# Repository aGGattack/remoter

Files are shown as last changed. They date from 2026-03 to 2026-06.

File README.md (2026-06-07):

# Bachelor Project - Wireless Remote Controller System

Remote control system for a robot, built around an **Adafruit Feather M0** with an **RFM69 433 MHz** radio, consisting of a handheld remote controller and a robot-side receiver.

---

## Repository Structure

```
bachelor/
├── remoter/                         # Firmware source code
│   ├── Remote/                      # Handheld remote controller
│   │   ├── src/main.cpp             # Main loop, 10Hz control rate
│   │   ├── src/RadioTrans.cpp       # RFM69 radio (TX, ACK)
│   │   ├── src/Joystick.cpp         # Analog joystick driver
│   │   ├── src/OledDis.cpp          # SSD1306 OLED display driver
│   │   ├── include/                 # Headers
│   │   └── platformio.ini           # PlatformIO config
│   │
│   └── RobotSide/                   # Robot-mounted receiver
│       ├── src/main.cpp             # Main loop, serial bridge
│       ├── src/RemoteTransiver.cpp  # RFM69 radio (RX, ACK) + serial
│       ├── include/                 # Headers
│       └── platformio.ini           # PlatformIO config
│
├── UniRemote/                       # Remote controller PCB (KiCad)
│   ├── PCB remote.kicad_sch         # Schematic
│   ├── PCB remote.kicad_pcb         # PCB layout
│   ├── PCB remote.kicad_pro         # Project file
│   └── Remote-footprints.pretty/    # Custom footprints
│
├── UniRobot/                        # Robot receiver PCB (KiCad)
│   ├── UniRobot.kicad_sch           # Schematic
│   ├── UniRobot.kicad_pcb           # PCB layout
│   ├── UniRobot.kicad_pro           # Project file
│   └── Remote-footprints.pretty/    # Custom footprints
│
├── Project tests/                   # RFM69 performance characterization
│   ├── BitRateLatencyTest.py        # Latency vs bitrate (1.2-250 kbps)
│   ├── PackageSizeLatencyTest.py    # Latency vs packet size (5-64 B)
│   ├── MaxDistance/                 # Packet loss vs distance
│   ├── RSSI_Antenna_test/           # RSSI vs distance + antenna length
│   ├── OrrientationTest/            # RSSI vs antenna orientation
│   └── latency_Bitrate_test/        # Plotting scripts
│
├── project_plan/                    # Project plan (LaTeX, diagrams)
├── Bachelor_Contract.pdf
├── appendix_code_listings.tex       # Full source listings for report
├── UniRemote v1.zip, v1.5.zip, ...  # PCB version archives
└── UniRobot v1.zip, v1.5.zip, ...
```

---

## Hardware

| Component | Description |
|---|---|
| **MCU** | Adafruit Feather M0 (ATSAMD21G18A, ARM Cortex-M0+) |
| **Radio** | RFM69HCW 433 MHz transceiver |
| **Display** | SSD1306 128x32 OLED, I2C |
| **Input** | Analog dual-axis joystick + push button (E-stop) |
| **Battery** | LiPo with voltage monitor via A7 |

---

## Firmware

### How It Works

- **Remote** reads joystick X/Y (8-bit), button state, and battery voltage. Transmits 3-byte packets every 100 ms to the robot (NodeID=1). Receives ACK containing robot battery voltage and robot name. Displays RSSI, local & remote battery, and robot name on the OLED.
- **RobotSide** receives joystick packets and forwards them over serial to a Raspberry Pi as `x:<val>, y:<val>, btn:<val>`. Sends ACKs with robot battery and name (parsed from Pi serial input `name:<n>,bat:<v>`). Drives an E-stop output pin.

### Prerequisites

- [PlatformIO](https://platformio.org/)

### Build & Upload

```bash
# Remote controller
cd remoter/Remote
pio run -e adafruit_feather_m0 --target upload

# Robot-side receiver
cd remoter/RobotSide
pio run -e adafruit_feather_m0 --target upload
```

### Serial Monitor

```bash
pio device monitor --baud 115200
```

---

## PCB Design

Both PCBs designed in **KiCad**. To open:

```
# Remote
UniRemote/PCB remote.kicad_pro

# Robot
UniRobot/UniRobot.kicad_pro
```

---

## RF Performance Tests

Python scripts in `Project tests/` characterize the RFM69 link:

| Test | What it measures |
|---|---|
| `BitRateLatencyTest.py` | One-way latency from 1.2 to 250 kbps |
| `PackageSizeLatencyTest.py` | Latency vs payload size at multiple bitrates |
| `MaxDistance/packagelossTest.py` | Packet loss ratio from 20 to 70 m |
| `RSSI_Antenna_test/RSSItest.py` | RSSI vs distance for a given antenna |
| `OrrientationTest/OrrientationsTest.py` | RSSI vs antenna orientation |
| Various `plot_*.py` | Generate plots from collected CSV data |

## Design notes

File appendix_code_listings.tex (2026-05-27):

% =============================================================================
% APPENDIX: Source Code Listings
% =============================================================================
% Fully self-contained -- works directly on Overleaf.
% Drop this file into your project and \input{appendix_code_listings}
% in your report where you want the appendix to appear.
%
% If you already have these packages in your preamble, comment out the
% \usepackage lines below.
% =============================================================================

% ---- Packages (uncomment any NOT already in your preamble) ------------------
% \usepackage{xcolor}
% \usepackage{listings}
% \usepackage{caption}

% ---- Listing style -----------------------------------------------------------
\definecolor{codebg}{rgb}{0.95,0.95,0.97}
\definecolor{codeframe}{rgb}{0.80,0.80,0.85}
\definecolor{stringgreen}{rgb}{0.15,0.55,0.15}
\definecolor{keywordblue}{rgb}{0.10,0.20,0.70}
\definecolor{commentgray}{rgb}{0.35,0.35,0.35}

\lstdefinestyle{appendix}{
  language        = C++,
  basicstyle      = \footnotesize\ttfamily,
  backgroundcolor = \color{codebg},
  frame           = single,
  rulecolor       = \color{codeframe},
  numbers         = left,
  numberstyle     = \tiny\color{gray},
  stepnumber      = 1,
  numbersep       = 8pt,
  tabsize         = 2,
  showspaces      = false,
  showstringspaces = false,
  breaklines      = true,
  breakatwhitespace = true,
  keywordstyle    = \color{keywordblue}\bfseries,
  commentstyle    = \color{commentgray}\itshape,
  stringstyle     = \color{stringgreen},
  captionpos      = t,
  xleftmargin     = 2em,
  framexleftmargin = 1.5em,
}

\lstdefinestyle{appendix-py}{
  style           = appendix,
  language        = Python,
}

\lstdefinestyle{appendix-ini}{
  style           = appendix,
  language        = {[LaTeX]TeX},
}

% =============================================================================
\chapter{Source Code Listings}  \label{app:code}
% =============================================================================

% -----------------------------------------------------------------------------
\section{Remote Controller Firmware (C++)}
% -----------------------------------------------------------------------------

The handheld remote controller firmware runs on an Adafruit Feather~M0
with an RFM69~433\,MHz transceiver, an SSD1306~128$\times$32~OLED display,
and an analog dual-axis joystick.  PlatformIO is used as the build system.

% ---- main.cpp ---------------------------------------------------------------
\begin{lstlisting}[style=appendix, caption={Remote --- main.cpp}, label={lst:remote-main}]
#include <Arduino.h>
#include "OledDis.h"
#include "RadioTrans.h"
#include "Joystick.h"

#define BUTTON_PIN 10
#define VBATPIN A7
#define PWR_CONTROL 5

volatile uint8_t buttonState = 0;

void handleButton() {
  buttonState = !buttonState;
}

void setup() {
  Serial.begin(115200);
  delay(2000);

  pinMode(PWR_CONTROL, OUTPUT);
  digitalWrite(PWR_CONTROL, HIGH);

  attachInterrupt(digitalPinToInterrupt(BUTTON_PIN), handleButton, FALLING);

  Display_init();

  transiver_init();   

  Serial.println("System ready");
}

void loop() {
  uint8_t x, y;
  int8_t RSSI = 0;
  uint8_t battery = 0;
  char robotName[15] = "No connection";

  readJoystick(&x, &y);

  // Remote battery mesurements
  float measuredvbat = analogRead(VBATPIN);
  measuredvbat *= 2;
  measuredvbat *= 3.3;
  measuredvbat /= 1024.0;

  sendData(x, y, buttonState, &battery, robotName, &RSSI);
  Display_draw(robotName, measuredvbat, battery, RSSI);

  delay(100);
}
\end{lstlisting}

% ---- Joystick.cpp -----------------------------------------------------------
\begin{lstlisting}[style=appendix, caption={Remote --- Joystick.cpp}, label={lst:remote-joystick}]
#include <Arduino.h>

void readJoystick(uint8_t *x, uint8_t *y) {
    *x = -analogRead(A0) >> 2;
    *y = -analogRead(A1) >> 2;
}
\end{lstlisting}

% ---- OledDis.cpp ------------------------------------------------------------
\begin{lstlisting}[style=appendix, caption={Remote --- OledDis.cpp}, label={lst:remote-oled}]
#include <Arduino.h>
#include "OledDis.h"
#include <Wire.h>
#include <Adafruit_SSD1306.h>

#define SCREEN_WIDTH 128
#define SCREEN_HEIGHT 32

Adafruit_SSD1306 display(
  SCREEN_WIDTH,
  SCREEN_HEIGHT,
  &Wire,     
  -1
);

void Display_init() {
  Wire.begin();
  delay(100);
  if (!display.begin(SSD1306_SWITCHCAPVCC, 0x3C)) {
    Serial.println("OLED not found");
    while (1);
  }
  Serial.println("OLED found");

  display.clearDisplay();
  display.setRotation(2);
  display.ssd1306_command(SSD1306_DISPLAYON);
  display.ssd1306_command(SSD1306_NORMALDISPLAY);
  display.display();
}

void Display_test() {
  display.clearDisplay();

  display.drawRect(0, 0, 128, 32, SSD1306_WHITE);

  display.drawLine(0, 0, 127, 31, SSD1306_WHITE);

  display.display();
}

void Display_clear() {
  display.clearDisplay();
  display.display();
}

void Display_draw(char *name, float remoteBattery, uint8_t robotBattery, int8_t RSSI) {
  display.clearDisplay();
  display.setTextSize(1);
  display.setTextColor(SSD1306_WHITE);
  display.setCursor(0, 0);

  display.print("Name:");
  display.println(name);

  display.print("R:");
  display.print(remoteBattery, 1);
  display.print("V");

  display.print("B:");
  display.print(robotBattery / 10.0, 1);
  display.println("V");

  display.print("RSSI:");
  display.println(RSSI);

  display.display();
}
\end{lstlisting}

% ---- RadioTrans.cpp ---------------------------------------------------------
\begin{lstlisting}[style=appendix, caption={Remote --- RadioTrans.cpp}, label={lst:remote-radio}]
#include "RadioTrans.h"
#include <SPI.h>
#include <RFM69.h>
#include <RFM69registers.h>

#define RFM69_CS    0
#define RFM69_RST   1
#define RFM69_INT   A4
#define RFM69_DIO2  A3
#define RFM69_DIO3  A5

#define NETWORKID   42
#define NODEID      2
#define TONODEID    1
#define FREQUENCY   RF69_433MHZ
#define LATENCY_PACKET 0x42
#define PACKET_TEST 0x55

RFM69 radio(RFM69_CS, RFM69_INT);

void transiver_init()
{
    pinMode(RFM69_RST, OUTPUT);
    digitalWrite(RFM69_RST, HIGH);
    delay(50);
    digitalWrite(RFM69_RST, LOW);
    delay(50);

    SPI.begin();

    if (!radio.initialize(FREQUENCY, NODEID, NETWORKID))
    {
        Serial.println("RFM69 init FAILED");
        while (1);
    }

    radio.setHighPower();

    Serial.println("RFM69 init OK");
}

bool sendData(uint8_t x, uint8_t y, uint8_t button, uint8_t *battery, char *robotName, int8_t *RSSI)
{
    uint8_t packet[3];
    packet[0] = x;
    packet[1] = y;
    packet[2] = button;

    if (!radio.sendWithRetry(TONODEID, packet, sizeof(packet), 1, 50))
    {
        Serial.println("No ACK received");
        return false;
    }

    *battery = radio.DATA[0];

    for (int i = 0; i < 14; i++)
    {
        robotName[i] = (char)radio.DATA[i + 1];

        if (robotName[i] == '\0')
            break;
    }

    robotName[14] = '\0';

    *RSSI = radio.RSSI;

    return true;
}
\end{lstlisting}

% ---- Joystick.h -------------------------------------------------------------
\begin{lstlisting}[style=appendix, caption={Remote --- Joystick.h}, label={lst:remote-joystick-h}]
#include <Arduino.h>

void readJoystick(uint8_t *x, uint8_t *y);
\end{lstlisting}

% ---- OledDis.h --------------------------------------------------------------
\begin{lstlisting}[style=appendix, caption={Remote --- OledDis.h}, label={lst:remote-oled-h}]
#pragma once
#include <Arduino.h>

void Display_init();
void Display_test();
void Display_clear();
void Display_draw(char *name, float remoteBattery, uint8_t robotBattery, int8_t RSSI);
\end{lstlisting}

% ---- RadioTrans.h -----------------------------------------------------------
\begin{lstlisting}[style=appendix, caption={Remote --- RadioTrans.h}, label={lst:remote-radio-h}]
#ifndef RFM69_H
#define RFM69_H

#include <Arduino.h>

void transiver_init();

bool sendData(uint8_t x, uint8_t y, uint8_t button, uint8_t *battery, char *robotName, int8_t *RSSI);

#endif
\end{lstlisting}

% ---- platformio.ini ---------------------------------------------------------
\begin{lstlisting}[style=appendix-ini, caption={Remote --- platformio.ini}, label={lst:remote-pio}]
[env:adafruit_feather_m0]
platform = atmelsam
board = adafruit_feather_m0
framework = arduino
monitor_speed = 115200
build_flags = -D USB_SERIAL
lib_deps = 
	adafruit/Adafruit SSD1306@^2.5.16
	lowpowerlab/RFM69@^1.6.0
	lowpowerlab/SPIFlash@^101.1.3
\end{lstlisting}

% -----------------------------------------------------------------------------
\section{Robot-Side Firmware (C++)}
% -----------------------------------------------------------------------------

The robot-side firmware runs on a second Adafruit Feather~M0.  It receives
joystick data over the RFM69 link, reads battery voltage and a human-readable
name from a Raspberry Pi over the serial port, and echoes these back to the
remote inside the radio's ACK payload.

% ---- Robot main.cpp ---------------------------------------------------------
\begin{lstlisting}[style=appendix, caption={Robot --- main.cpp}, label={lst:robot-main}]
#include <Arduino.h>
#include <SPI.h>
#include <RFM69.h>
#include "RemoteTransiver.h"

void setup() {
  Serial.begin(115200);
  while (!Serial) delay(10);

  transiver_init();
}

void loop() {
  transiver_receive();
}
\end{lstlisting}

% ---- RemoteTransiver.cpp ----------------------------------------------------
\begin{lstlisting}[style=appendix, caption={Robot --- RemoteTransiver.cpp}, label={lst:robot-trans}]
#include <SPI.h>
#include <RFM69.h>
#include "RemoteTransiver.h"
#include <RFM69registers.h>

#define RFM69_CS   A5
#define RFM69_INT  6
#define RFM69_RST  A4
#define ESTOP      A3
#define LED_PIN    13

#define NETWORKID  42
#define NODEID     1
#define TONODEID   2
#define FREQUENCY  RF69_433MHZ
#define LATENCY_PACKET 0x42
#define PACKET_TEST 0x55

RFM69 radio(RFM69_CS, RFM69_INT);

float batteryVoltage = 0;       
char robotName[16] = "none/con";     
bool piDataReceived = false;     

unsigned long lastReceiveTime = 0;
unsigned long lastNoConnectionPrint = 0;
const unsigned long CONNECTION_TIMEOUT = 1000;

void transiver_init()
{
    pinMode(LED_PIN, OUTPUT);
    pinMode(RFM69_RST, OUTPUT);
    digitalWrite(RFM69_RST, HIGH);
    delay(100);
    digitalWrite(RFM69_RST, LOW);
    delay(100);

    pinMode(ESTOP, OUTPUT);

    if (!radio.initialize(FREQUENCY, NODEID, NETWORKID))
    {
        Serial.println("RFM69 init FAILED");
        while (1);
    }

    radio.setHighPower();

    Serial.println("RFM69 init OK");
    lastReceiveTime = millis();
}

void readPiSerial()
{
    static char line[64];
    static uint8_t idx = 0;

    while (Serial.available())
    {
        char c = Serial.read();
        if (c == '\r') continue;

        if (c == '\n')
        {
            line[idx] = '\0';
            idx = 0;

            // Find "name:" 
            char* namePtr = strstr(line, "name:");
            char* batPtr  = strstr(line, ",bat:");

            if (namePtr && batPtr)
            {
                namePtr += 5; // skip "name:"

                // Copy name up to the comma
                uint8_t i = 0;
                while (namePtr[i] != ',' && namePtr[i] != '\0' && i < 15)
                {
                    robotName[i] = namePtr[i];
                    i++;
                }
                robotName[i] = '\0';

                // Parse float manually
                batPtr += 5; // skip ",bat:"
                batteryVoltage = atof(batPtr);
                piDataReceived = true;

            }

        }
        else
        {
            if (idx < sizeof(line) - 1)
                line[idx++] = c;
            else
                idx = 0;
        }
    }
}

void handleDataPacket(uint8_t x, uint8_t y, uint8_t button)
{

    Serial.print("x:");
    Serial.print(x);
    Serial.print(", y:");
    Serial.print(y);
    Serial.print(", btn:");
    Serial.println(button);

    if (button == 1)
        digitalWrite(ESTOP, HIGH);
    else
        digitalWrite(ESTOP, LOW);
}

void transiver_receive()
{

    readPiSerial();

    if (radio.receiveDone())
    {
        if (radio.ACKRequested())
        {

            uint8_t ackPayload[16];

            // Battery voltage, e.g. 24.3V -> 243
            ackPayload[0] = (uint8_t)(batteryVoltage * 10.0);

            // Copy robot name into remaining bytes
            uint8_t i = 0;
            for (; i < 14 && robotName[i] != '\0'; i++)
            {
                ackPayload[i + 1] = robotName[i];
            }

            // Zero-fill rest
            for (; i < 14; i++)
            {
                ackPayload[i + 1] = 0;
            }

            radio.sendACK(ackPayload, 15);
        }

        uint8_t x      = radio.DATA[0];
        uint8_t y      = radio.DATA[1];
        uint8_t button = radio.DATA[2];

        handleDataPacket(x, y, button);
        lastReceiveTime = millis();
    }

    if (millis() - lastReceiveTime >= CONNECTION_TIMEOUT) {
        if (millis() - lastNoConnectionPrint >= 1000) {
            Serial.println("no connection"); 
            lastNoConnectionPrint = millis();
        }
    }
}
\end{lstlisting}

% ---- RemoteTransiver.h ------------------------------------------------------
\begin{lstlisting}[style=appendix, caption={Robot --- RemoteTransiver.h}, label={lst:robot-trans-h}]
#ifndef RFM69_H
#define RFM69_H

#include <Arduino.h>

void transiver_init();
void transiver_receive();
void readPiSerial();

#endif
\end{lstlisting}

% ---- Robot platformio.ini ---------------------------------------------------
\begin{lstlisting}[style=appendix-ini, caption={Robot --- platformio.ini}, label={lst:robot-pio}]
[env:adafruit_feather_m0]
platform = atmelsam
board = adafruit_feather_m0
framework = arduino
monitor_speed = 115200
build_flags = -D USB_SERIAL
lib_deps = 
	adafruit/Adafruit SSD1306@^2.5.16
	lowpowerlab/RFM69@^1.6.0
	lowpowerlab/SPIFlash@^101.1.3
\end{lstlisting}

% -----------------------------------------------------------------------------
\section{Test and Measurement Scripts (Python)}
% -----------------------------------------------------------------------------

The following Python scripts were used during the project to characterise
the radio link's latency, packet-loss, and signal-strength (RSSI)
performance.  All measurement scripts communicate with the robot-side
Feather~M0 over a serial port and use \texttt{matplotlib} to produce plots.

% ---- test_feather.py --------------------------------------------------------
\begin{lstlisting}[style=appendix-py, caption={Feather serial-communication test}, label={lst:test-feather}]
#!/usr/bin/env python3
"""
Feather M0 Communication Test Script
============================
Usage: python test_feather.py

This script tests serial communication with the Feather M0 (RobotSide).

Setup:
  - Windows: Uses COM8 (change below if different)
  - Linux: Uses /dev/ttyACM1 (change below if different)

Run:
  python test_feather.py

What it does:
  1. Sends "name:TESTBOT,bat:12.34\n" to Feather
  2. Waits for response
  3. Reports what was received

Output examples:
  - "Response: OK" = Feather received and responded
  - "No response" = Feather not receiving data
"""

import serial
import time
import sys

WINDOWS_PORT = 'COM8'
LINUX_PORT = '/dev/ttyACM1'

if sys.platform.startswith('win'):
    SERIAL_PORT = WINDOWS_PORT
elif sys.platform.startswith('linux'):
    SERIAL_PORT = LINUX_PORT
else:
    SERIAL_PORT = '/dev/ttyUSB0'  # Mac

BAUD_RATE = 115200
TIMEOUT = 2

def test_feather():
    print("=== Feather M0 Communication Test ===")
    print(f"Platform: {sys.platform}")
    print(f"Port: {SERIAL_PORT}")
    print(f"Baud: {BAUD_RATE}")
    print("-" * 40)

    try:
        print("Opening serial port...")
        ser = serial.Serial(SERIAL_PORT, BAUD_RATE, timeout=TIMEOUT)
        time.sleep(2)
        print("Port opened!")

        print("\nSending test data...")
        test_msg = "name:TESTBOT,bat:12.34\n"
        ser.write(test_msg.encode())
        print(f"Sent: {test_msg.strip()}")

        print("\nReading response...")
        received_any = False
        
        for i in range(3):
            time.sleep(0.5)
            if ser.in_waiting > 0:
                data = ser.read(ser.in_waiting)
                print(f"Response {i+1}: {data.decode('utf-8', errors='replace').strip()}")
                received_any = True
            else:
                print(f"Attempt {i+1}: No data available")

        if not received_any:
            print("\nNo response received from Feather!")
            print("This means Feather is not responding to the serial data.")

        ser.close()
        print("\n=== Test Complete ===")

    except serial.SerialException as e:
        print(f"\nERROR: {e}")
        print("\nTroubleshooting:")
        print("  - Make sure Feather is connected")
        print("  - Check correct COM port (Windows: COMx, Linux: /dev/ttyACMx)")
        print("  - Close other programs using the port")
        print("  - Try a different USB port")

if __name__ == "__main__":
    test_feather()
\end{lstlisting}

% ---- BitRateLatencyTest.py --------------------------------------------------
\begin{lstlisting}[style=appendix-py, caption={Latency vs.\ bitrate measurement}, label={lst:bitrate-latency}]
import serial
import time
import matplotlib.pyplot as plt
import csv
import re
from datetime import datetime

SERIAL_PORT = "COM8"
BAUD_RATE = 115200

BITRATE_LABEL = "1.2 kbps"   # Change this manually for each test
MEASURE_TIME = 10

timestamp = datetime.now().strftime("%Y%m%d_%H%M%S")

csv_filename = f"latency_{BITRATE_LABEL.replace(' ', '_')}_{timestamp}.csv"
plot_filename = f"latency_{BITRATE_LABEL.replace(' ', '_')}_{timestamp}.png"

ser = serial.Serial(SERIAL_PORT, BAUD_RATE, timeout=1)
time.sleep(2)

rtt_values = []
oneway_values = []

pattern = r"RTT:\s+(\d+)\s+us\s+\|\s+One-way latency:\s+([\d.]+)\s+ms"

print(f"\nRecording latency data for {BITRATE_LABEL}...")

start = time.time()

while time.time() - start < MEASURE_TIME:
    line = ser.readline().decode(errors='ignore').strip()
    match = re.search(pattern, line)

    if match:
        rtt = int(match.group(1))
        latency = float(match.group(2))
        rtt_values.append(rtt)
        oneway_values.append(latency)
        print(f"RTT: {rtt} us | Latency: {latency} ms")

ser.close()

print(f"\nCollected {len(rtt_values)} samples")

with open(csv_filename, mode='w', newline='') as file:
    writer = csv.writer(file)
    writer.writerow(["Sample", "Bitrate", "RTT_us", "OneWayLatency_ms"])
    for i in range(len(rtt_values)):
        writer.writerow([i + 1, BITRATE_LABEL, rtt_values[i], oneway_values[i]])

print(f"CSV saved as: {csv_filename}")

avg_latency = sum(oneway_values) / len(oneway_values)

samples = list(range(1, len(oneway_values) + 1))

plt.figure(figsize=(8,5))
plt.plot(samples, oneway_values, marker='o', label="One-way Latency")
plt.axhline(avg_latency, linestyle='--', label=f"Average = {avg_latency:.3f} ms")
plt.xlabel("Sample Number")
plt.ylabel("Latency (ms)")
plt.title(f"Latency Test - {BITRATE_LABEL}")
plt.grid(True)
plt.legend()
plt.tight_layout()
plt.savefig(plot_filename, dpi=300)
print(f"Plot saved as: {plot_filename}")
plt.show()
\end{lstlisting}

% ---- PackageSizeLatencyTest.py ----------------------------------------------
\begin{lstlisting}[style=appendix-py, caption={Latency vs.\ packet-size measurement}, label={lst:pkt-size-latency}]
import serial
import time
import matplotlib.pyplot as plt
import csv
import re
from datetime import datetime

SERIAL_PORT = "COM8"
BAUD_RATE = 115200

PACKET_SIZE = 5     # Change for each test
BIT_RATE = 115.2
MEASURE_TIME = 10

timestamp = datetime.now().strftime("%Y%m%d_%H%M%S")

csv_filename = f"packet_size_{PACKET_SIZE}B_{BIT_RATE}kb{timestamp}.csv"
plot_filename = f"packet_size_{PACKET_SIZE}B_{BIT_RATE}kb{timestamp}.png"

ser = serial.Serial(SERIAL_PORT, BAUD_RATE, timeout=1)
time.sleep(2)

rtt_values = []
latency_values = []

pattern = r"Size:\s+(\d+)\s+bytes\s+\|\s+RTT:\s+(\d+)\s+us\s+\|\s+One-way latency:\s+([\d.]+)\s+ms"

print(f"\nRecording latency data for packet size = {PACKET_SIZE} bytes")

start = time.time()

while time.time() - start < MEASURE_TIME:
    line = ser.readline().decode(errors='ignore').strip()
    match = re.search(pattern, line)

    if match:
        size = int(match.group(1))
        rtt = int(match.group(2))
        latency = float(match.group(3))
        rtt_values.append(rtt)
        latency_values.append(latency)
        print(f"Size: {size} B | RTT: {rtt} us | Latency: {latency} ms")

ser.close()

print(f"\nCollected {len(latency_values)} samples")

with open(csv_filename, mode='w', newline='') as file:
    writer = csv.writer(file)
    writer.writerow(["Sample", "PacketSize_Bytes", "RTT_us", "OneWayLatency_ms"])
    for i in range(len(latency_values)):
        writer.writerow([i + 1, PACKET_SIZE, rtt_values[i], latency_values[i]])

print(f"CSV saved as: {csv_filename}")

avg_latency = sum(latency_values) / len(latency_values)

samples = list(range(1, len(latency_values) + 1))

plt.figure(figsize=(8,5))
plt.plot(samples, latency_values, marker='o', label="One-way Latency")
plt.axhline(avg_latency, linestyle='--', label=f"Average = {avg_latency:.3f} ms")
plt.xlabel("Sample Number")
plt.ylabel("Latency (ms)")
plt.title(f"Latency vs Time - Packet Size {PACKET_SIZE} Bytes")
plt.grid(True)
plt.legend()
plt.tight_layout()
plt.savefig(plot_filename, dpi=300)
print(f"Plot saved as: {plot_filename}")
plt.show()
\end{lstlisting}

% ---- packagelossTest.py -----------------------------------------------------
\begin{lstlisting}[style=appendix-py, caption={Packet loss vs.\ distance}, label={lst:packet-loss}]
import serial
import time
import matplotlib.pyplot as plt
import csv
from datetime import datetime

SERIAL_PORT = "COM8"
BAUD_RATE = 115200

DISTANCES = list([20, 40, 50, 70])
EXPECTED_PACKETS = 100

timestamp = datetime.now().strftime("%Y%m%d_%H%M%S")

csv_filename = f"packet_loss_test_{timestamp}.csv"
plot_filename = f"packet_loss_plot_{timestamp}.png"

ser = serial.Serial(SERIAL_PORT, BAUD_RATE, timeout=1)
time.sleep(2)

results = {}

for dist in DISTANCES:
    print(f"\nMove robot to {dist} meters")
    input("Press ENTER when ready...")
    print("Waiting for packets...")

    received_packets = set()
    start_time = time.time()

    while time.time() - start_time < 10:
        line = ser.readline().decode(errors='ignore').strip()

        if "Received packet:" in line:
            try:
                packet_num = int(line.split(":")[1])
                received_packets.add(packet_num)
                print(f"{dist}m -> Packet {packet_num}")
            except:
                pass

    received_count = len(received_packets)
    lost_count = EXPECTED_PACKETS - received_count
    loss_percent = (lost_count / EXPECTED_PACKETS) * 100

    results[dist] = {
        "received": received_count,
        "lost": lost_count,
        "loss_percent": loss_percent
    }

    print("\n========== RESULT ==========")
    print(f"Distance: {dist} m")
    print(f"Received: {received_count}")
    print(f"Lost: {lost_count}")
    print(f"Packet Loss: {loss_percent:.1f}%")
    print("============================")

ser.close()

with open(csv_filename, mode='w', newline='') as file:
    writer = csv.writer(file)
    writer.writerow(["Distance_m", "Received_Packets", "Lost_Packets", "Packet_Loss_Percent"])
    for dist in DISTANCES:
        writer.writerow([dist, results[dist]["received"], results[dist]["lost"], results[dist]["loss_percent"]])

print(f"\nCSV saved as: {csv_filename}")

distances = [dist for dist in DISTANCES]
losses = [results[dist]["loss_percent"] for dist in DISTANCES]

plt.figure(figsize=(8, 5))
plt.plot(distances, losses, marker='o')
plt.xlabel("Distance (m)")
plt.ylabel("Packet Loss (%)")
plt.title("Packet Loss vs Distance")
plt.grid(True)
plt.tight_layout()
plt.savefig(plot_filename, dpi=300)
print(f"Plot saved as: {plot_filename}")
plt.show()
\end{lstlisting}

% ---- OrrientationsTest.py ---------------------------------------------------
\begin{lstlisting}[style=appendix-py, caption={RSSI vs.\ antenna orientation}, label={lst:orientation}]
import serial
import time
import matplotlib.pyplot as plt
import csv
from datetime import datetime

SERIAL_PORT = "COM8"
BAUD_RATE = 115200

ORIENTATIONS = ["Front", "Back", "Left", "Right"]
MEASURE_TIME = 10
ANTENNA = "Horizontal_16.5cm"

timestamp = datetime.now().strftime("%Y%m%d_%H%M%S")

csv_filename = f"rssi_orientation_data_{ANTENNA}_{timestamp}.csv"
plot_filename = f"rssi_orientation_plot_{ANTENNA}_{timestamp}.png"

ser = serial.Serial(SERIAL_PORT, BAUD_RATE, timeout=1)
time.sleep(2)

results = {}

def parse_line(line):
    try:
        parts = line.split(",")
        x = int(parts[0].split(":")[1])
        rssi = int(parts[1].split(":")[1])
        return x, rssi
    except:
        return None, None

for orientation in ORIENTATIONS:
    print(f"\nRotate robot to: {orientation}")
    print("Push joystick to start recording...")

    while True:
        line = ser.readline().decode().strip()
        x, rssi = parse_line(line)
        if x is not None and x > 240:
            print(f"Recording {orientation} orientation...")
            break

    rssi_values = []
    start = time.time()

    while time.time() - start < MEASURE_TIME:
        line = ser.readline().decode().strip()
        x, rssi = parse_line(line)
        if rssi is not None:
            rssi_values.append(rssi)

    results[orientation] = rssi_values
    print(f"Collected {len(rssi_values)} samples")

ser.close()

with open(csv_filename, mode='w', newline='') as file:
    writer = csv.writer(file)
    writer.writerow(["Orientation", "Sample_Number", "RSSI_dBm"])
    for orientation in ORIENTATIONS:
        for i, rssi in enumerate(results[orientation]):
            writer.writerow([orientation, i + 1, rssi])

print(f"\nCSV data saved as: {csv_filename}")

orientations = []
means = []
mins = []
maxs = []

for orientation in ORIENTATIONS:
    vals = results[orientation]
    if len(vals) == 0:
        continue
    orientations.append(orientation)
    means.append(sum(vals) / len(vals))
    mins.append(min(vals))
    maxs.append(max(vals))

plt.figure(figsize=(8, 5))
plt.plot(orientations, means, marker='o', label="Average RSSI")
plt.fill_between(range(len(orientations)), mins, maxs, alpha=0.2, label="Variation")
plt.xlabel("Orientation")
plt.ylabel("RSSI (dBm)")
plt.title("RSSI vs Orientation")
plt.grid(True)
plt.legend()
plt.tight_layout()
plt.savefig(plot_filename, dpi=300)
print(f"Plot saved as: {plot_filename}")
plt.show()
\end{lstlisting}

% ---- RSSItest.py ------------------------------------------------------------
\begin{lstlisting}[style=appendix-py, caption={RSSI vs.\ distance and antenna length}, label={lst:rssi-test}]
import serial
import time
import matplotlib.pyplot as plt
import csv
from datetime import datetime

SERIAL_PORT = "COM8"
BAUD_RATE = 115200

DISTANCES = [1, 5, 10, 20, 40]
MEASURE_TIME = 10
ANTENNA = "Horizontal_16.5cm"

timestamp = datetime.now().strftime("%Y%m%d_%H%M%S")

csv_filename = f"rssi_data_{ANTENNA}_{timestamp}.csv"
plot_filename = f"rssi_plot_{ANTENNA}_{timestamp}.png"

ser = serial.Serial(SERIAL_PORT, BAUD_RATE, timeout=1)
time.sleep(2)

results = {}

def parse_line(line):
    try:
        parts = line.split(",")
        x = int(parts[0].split(":")[1])
        rssi = int(parts[1].split(":")[1])
        return x, rssi
    except:
        return None, None

for dist in DISTANCES:
    print(f"\nMove to {dist} meters. Push joystick to start...")

    while True:
        line = ser.readline().decode().strip()
        x, rssi = parse_line(line)
        if x is not None and x > 240:
            print(f"Recording at {dist} m...")
            break

    rssi_values = []
    start = time.time()

    while time.time() - start < MEASURE_TIME:
        line = ser.readline().decode().strip()
        x, rssi = parse_line(line)
        if rssi is not None:
            rssi_values.append(rssi)

    results[dist] = rssi_values
    print(f"Collected {len(rssi_values)} samples")

ser.close()

with open(csv_filename, mode='w', newline='') as file:
    writer = csv.writer(file)
    writer.writerow(["Distance_m", "Sample_Number", "RSSI_dBm"])
    for dist in DISTANCES:
        for i, rssi in enumerate(results[dist]):
            writer.writerow([dist, i + 1, rssi])

print(f"\nCSV data saved as: {csv_filename}")

distances = []
means = []
mins = []
maxs = []

for d in DISTANCES:
    vals = results[d]
    if len(vals) == 0:
        continue
    distances.append(d)
    means.append(sum(vals) / len(vals))
    mins.append(min(vals))
    maxs.append(max(vals))

plt.figure()
plt.plot(distances, means, marker='o', label="Average RSSI")
plt.fill_between(distances, mins, maxs, alpha=0.2, label="Variation")
plt.xlabel("Distance (m)")
plt.ylabel("RSSI (dBm)")
plt.title("RSSI vs Distance")
plt.grid(True)
plt.legend()
plt.tight_layout()
plt.savefig(plot_filename, dpi=300)
print(f"Plot saved as: {plot_filename}")
plt.show()
\end{lstlisting}

% ---- plot_rssi_antenna.py ---------------------------------------------------
\begin{lstlisting}[style=appendix-py, caption={Multi-file RSSI plotting (antenna comparison)}, label={lst:rssi-plot}]
"""
RSSI vs Distance -- comparison across antenna lengths.

Filename format:  rssi_data_*_<LENGTH>cm_<timestamp>.csv
Columns: Distance_m, Sample_Number, RSSI_dBm
"""

import os
import re
import glob
import pandas as pd
import numpy as np
import matplotlib.pyplot as plt
import matplotlib.ticker as ticker
from pathlib import Path
from collections import defaultdict

DATA_DIR = os.path.dirname(os.path.abspath(__file__))
OUTPUT_DIR = DATA_DIR

LENGTH_ORDER = [16.5, 16.7, 16.9, 17.1, 17.3, 17.5, 17.8]

PALETTE = ["#1f77b4", "#ff7f0e", "#2ca02c", "#d62728",
           "#9467bd", "#8c564b", "#e377c2"]

def parse_length(path: str):
    m = re.search(r'_([\d]+[_.][\d]+)cm[_.]', Path(path).name)
    if m:
        return float(m.group(1).replace("_", "."))
    m2 = re.search(r'_(\d+)cm[_.]', Path(path).name)
    if m2:
        return float(m2.group(1))
    return None

def load_all(data_dir: str) -> pd.DataFrame:
    pattern = os.path.join(data_dir, "rssi_data_*.csv")
    files = glob.glob(pattern)
    if not files:
        raise FileNotFoundError(f"No files matching 'rssi_data_*.csv' in {data_dir}")

    by_length = defaultdict(list)
    for f in sorted(files):
        length = parse_length(f)
        if length is None:
            continue
        df = pd.read_csv(f)
        df.columns = [c.strip() for c in df.columns]
        df = df.rename(columns={c: c.lower().replace(" ", "_") for c in df.columns})
        df = df.rename(columns={"distance_m": "distance", "rssi_dbm": "rssi"})
        df["length_cm"] = length
        by_length[length].append(df)

    frames = []
    for length, dfs in sorted(by_length.items()):
        frames.append(pd.concat(dfs, ignore_index=True))
    return pd.concat(frames, ignore_index=True)

def build_stats(df: pd.DataFrame) -> pd.DataFrame:
    g = df.groupby(["length_cm", "distance"])["rssi"]
    stats = pd.DataFrame({
        "mean": g.mean(), "median": g.median(), "std": g.std(),
        "p5": g.quantile(0.05), "p95": g.quantile(0.95), "n": g.count(),
    }).reset_index()
    return stats

def plot_rssi_vs_distance(stats: pd.DataFrame, out_dir: str):
    lengths = sorted(stats["length_cm"].unique(),
                     key=lambda x: LENGTH_ORDER.index(x) if x in LENGTH_ORDER else x)
    fig, ax = plt.subplots(figsize=(9, 6))
    for i, length in enumerate(lengths):
        sub = stats[stats["length_cm"] == length].sort_values("distance")
        color = PALETTE[i % len(PALETTE)]
        marker = ["o", "s", "^", "D", "v", "P", "X"][i % 7]
        ax.plot(sub["distance"], sub["median"],
                color=color, marker=marker, linewidth=2, markersize=7,
                label=f"{length} cm", zorder=3)
        ax.fill_between(sub["distance"], sub["p5"], sub["p95"],
                        alpha=0.08, color=color)
        ax.fill_between(sub["distance"],
                        sub["median"] - sub["std"], sub["median"] + sub["std"],
                        alpha=0.15, color=color)
    ax.set_xscale("log")
    ax.set_xlabel("Distance (m)", fontsize=11)
    ax.set_ylabel("RSSI (dBm)", fontsize=11)
    ax.set_title("RSSI vs Distance -- Antenna Length Comparison", fontsize=12)
    distances = sorted(stats["distance"].unique())
    ax.set_xticks(distances)
    ax.set_xticklabels([f"{d} m" for d in distances])
    ax.xaxis.set_minor_formatter(ticker.NullFormatter())
    ax.legend(title="Antenna length", loc="lower left")
    ax.grid(True, which="both", linestyle="--", alpha=0.4)
    fig.tight_layout()
    fig.savefig(os.path.join(out_dir, "plot_rssi_vs_distance.png"), dpi=150)
    plt.close(fig)

def plot_bar_per_distance(stats: pd.DataFrame, out_dir: str):
    lengths = sorted(stats["length_cm"].unique(),
                     key=lambda x: LENGTH_ORDER.index(x) if x in LENGTH_ORDER else x)
    distances = sorted(stats["distance"].unique())
    n_len = len(lengths)
    x = np.arange(len(distances))
    width = 0.7 / n_len
    offsets = np.linspace(-(n_len - 1) / 2, (n_len - 1) / 2, n_len) * width
    fig, ax = plt.subplots(figsize=(11, 6))
    for i, length in enumerate(lengths):
        sub = stats[stats["length_cm"] == length].sort_values("distance")
        vals = [sub[sub["distance"] == d]["median"].values[0]
                if len(sub[sub["distance"] == d]) else np.nan for d in distances]
        errs = [sub[sub["distance"] == d]["std"].values[0]
                if len(sub[sub["distance"] == d]) else 0 for d in distances]
        ax.bar(x + offsets[i], vals, width, yerr=errs,
               color=PALETTE[i], alpha=0.8, label=f"{length} cm", capsize=3)
    ax.set_xticks(x)
    ax.set_xticklabels([f"{d} m" for d in distances])
    ax.set_ylabel("Median RSSI (dBm)")
    ax.set_title("Median RSSI per Distance -- Antenna Length Comparison")
    ax.legend(loc="lower left")
    ax.grid(axis="y", linestyle="--", alpha=0.4)
    fig.tight_layout()
    fig.savefig(os.path.join(out_dir, "plot_rssi_bar_per_distance.png"), dpi=150)
    plt.close(fig)

def plot_boxplot_far(df: pd.DataFrame, out_dir: str):
    max_dist = df["distance"].max()
    sub = df[df["distance"] == max_dist]
    lengths = sorted(sub["length_cm"].unique(),
                     key=lambda x: LENGTH_ORDER.index(x) if x in LENGTH_ORDER else x)
    groups = [sub[sub["length_cm"] == l]["rssi"].values for l in lengths]
    labels = [f"{l} cm" for l in lengths]
    colors = PALETTE[:len(lengths)]
    fig, ax = plt.subplots(figsize=(9, 5))
    bp = ax.boxplot(groups, tick_labels=labels, patch_artist=True,
                    medianprops={"color": "black", "linewidth": 2})
    for patch, color in zip(bp["boxes"], colors):
        patch.set_facecolor(color)
        patch.set_alpha(0.75)
    ax.set_title(f"RSSI Distribution at {max_dist} m")
    ax.grid(axis="y", linestyle="--", alpha=0.4)
    fig.tight_layout()
    fig.savefig(os.path.join(out_dir, f"plot_rssi_boxplot_{max_dist}m.png"), dpi=150)
    plt.close(fig)

if __name__ == "__main__":
    df = load_all(DATA_DIR)
    stats = build_stats(df)
    os.makedirs(OUTPUT_DIR, exist_ok=True)
    plot_rssi_vs_distance(stats, OUTPUT_DIR)
    plot_bar_per_distance(stats, OUTPUT_DIR)
    plot_boxplot_far(df, OUTPUT_DIR)
\end{lstlisting}

% ---- plot_latency_vs_bitrate.py ---------------------------------------------
\begin{lstlisting}[style=appendix-py, caption={Latency vs.\ bitrate plotting}, label={lst:latency-bitrate-plot}]
"""
Latency vs Bitrate -- fixed packet size (5 B).

Loads all CSVs matching: latency_*kbps*.csv
Columns: Sample, Bitrate (string), RTT_us, OneWayLatency_ms
"""

import os, re, glob
import pandas as pd
import numpy as np
import matplotlib.pyplot as plt
import matplotlib.ticker as ticker
from pathlib import Path

DATA_DIR = os.path.dirname(os.path.abspath(__file__))
OUTPUT_DIR = DATA_DIR
PACKET_SIZE_B = 5
BITRATE_ORDER = [1.2, 9.6, 57.6, 115.2, 250.0]

def load_all_csvs(data_dir: str) -> pd.DataFrame:
    pattern = os.path.join(data_dir, "latency_*kbps*.csv")
    files = glob.glob(pattern)
    if not files:
        raise FileNotFoundError(f"No CSVs matching 'latency_*kbps*.csv' in {data_dir}")
    frames = []
    for f in sorted(files):
        df = pd.read_csv(f)
        df.columns = [c.strip() for c in df.columns]
        col_map = {c: ["sample", "bitrate_str", "RTT_us", "OWL_ms"][i]
                   for i, c in enumerate(df.columns)}
        df = df.rename(columns=col_map)
        frames.append(df)
    combined = pd.concat(frames, ignore_index=True)
    combined["bitrate_kbps"] = combined["bitrate_str"].str.extract(r"([\d.]+)").astype(float)
    return combined

def remove_outliers(df: pd.DataFrame) -> pd.DataFrame:
    clean = []
    for br, g in df.groupby("bitrate_kbps"):
        med = g["RTT_us"].median()
        clean.append(g[g["RTT_us"] < 5 * med])
    return pd.concat(clean, ignore_index=True)

def build_stats(df: pd.DataFrame) -> pd.DataFrame:
    g = df.groupby("bitrate_kbps")["RTT_us"]
    stats = pd.DataFrame({
        "n": g.count(), "mean_ms": g.mean()/1000, "median_ms": g.median()/1000,
        "std_ms": g.std()/1000, "p5_ms": g.quantile(0.05)/1000,
        "p95_ms": g.quantile(0.95)/1000,
    }).reset_index()
    order = {b: i for i, b in enumerate(BITRATE_ORDER)}
    stats["_order"] = stats["bitrate_kbps"].map(order).fillna(999)
    return stats.sort_values("_order").drop(columns="_order").reset_index(drop=True)

def plot_rtt_line(stats: pd.DataFrame, out_dir: str):
    fig, ax = plt.subplots(figsize=(8, 5))
    ax.plot(stats["bitrate_kbps"], stats["median_ms"],
            color="#2196F3", marker="o", linewidth=2, markersize=7, zorder=3,
            label="Median RTT")
    ax.fill_between(stats["bitrate_kbps"], stats["p5_ms"], stats["p95_ms"],
                    alpha=0.15, color="#2196F3", label="5th-95th percentile")
    ax.fill_between(stats["bitrate_kbps"],
                    stats["median_ms"] - stats["std_ms"],
                    stats["median_ms"] + stats["std_ms"],
                    alpha=0.25, color="#2196F3", label=r"$\pm1\sigma$")
    for _, row in stats.iterrows():
        ax.annotate(f"{row['median_ms']:.1f} ms",
                    xy=(row["bitrate_kbps"], row["median_ms"]),
                    xytext=(0, 10), textcoords="offset points", ha="center", fontsize=8)
    ax.set_xscale("log")
    ax.set_xlabel("Bitrate (kbps)")
    ax.set_ylabel("RTT (ms)")
    ax.set_title(f"Round-Trip Time vs Bitrate  |  Packet size = {PACKET_SIZE_B} B")
    ax.set_xticks(stats["bitrate_kbps"])
    ax.set_xticklabels([f"{b:g}" for b in stats["bitrate_kbps"]])
    ax.xaxis.set_minor_formatter(ticker.NullFormatter())
    ax.legend()
    ax.grid(True, which="both", linestyle="--", alpha=0.4)
    fig.tight_layout()
    fig.savefig(os.path.join(out_dir, "plot_rtt_vs_bitrate.png"), dpi=150)
    plt.close(fig)

def plot_owl_line(df: pd.DataFrame, out_dir: str):
    owl = df.groupby("bitrate_kbps")["OWL_ms"]
    owl_stats = pd.DataFrame({
        "median_ms": owl.median(), "std_ms": owl.std(),
        "p5_ms": owl.quantile(0.05), "p95_ms": owl.quantile(0.95),
    }).reset_index()
    order = {b: i for i, b in enumerate(BITRATE_ORDER)}
    owl_stats["_order"] = owl_stats["bitrate_kbps"].map(order).fillna(999)
    owl_stats = owl_stats.sort_values("_order").drop(columns="_order").reset_index(drop=True)
    fig, ax = plt.subplots(figsize=(8, 5))
    ax.plot(owl_stats["bitrate_kbps"], owl_stats["median_ms"],
            color="#4CAF50", marker="s", linewidth=2, markersize=7, zorder=3,
            label="Median one-way latency")
    ax.fill_between(owl_stats["bitrate_kbps"],
                    owl_stats["median_ms"] - owl_stats["std_ms"],
                    owl_stats["median_ms"] + owl_stats["std_ms"],
                    alpha=0.25, color="#4CAF50", label=r"$\pm1\sigma$")
    for _, row in owl_stats.iterrows():
        ax.annotate(f"{row['median_ms']:.1f} ms",
                    xy=(row["bitrate_kbps"], row["median_ms"]),
                    xytext=(0, 10), textcoords="offset points", ha="center", fontsize=8)
    ax.set_xscale("log")
    ax.set_xlabel("Bitrate (kbps)")
    ax.set_ylabel("One-Way Latency (ms)")
    ax.set_title(f"One-Way Latency vs Bitrate  |  Packet size = {PACKET_SIZE_B} B")
    ax.set_xticks(owl_stats["bitrate_kbps"])
    ax.set_xticklabels([f"{b:g}" for b in owl_stats["bitrate_kbps"]])
    ax.xaxis.set_minor_formatter(ticker.NullFormatter())
    ax.legend()
    ax.grid(True, which="both", linestyle="--", alpha=0.4)
    fig.tight_layout()
    fig.savefig(os.path.join(out_dir, "plot_owl_vs_bitrate.png"), dpi=150)
    plt.close(fig)

def plot_boxplot(df: pd.DataFrame, out_dir: str):
    stats = build_stats(df)
    bitrates = stats["bitrate_kbps"].tolist()
    groups = [df[df["bitrate_kbps"] == br]["RTT_us"].values / 1000 for br in bitrates]
    labels = [f"{b:g} kbps" for b in bitrates]
    fig, ax = plt.subplots(figsize=(9, 5))
    bp = ax.boxplot(groups, tick_labels=labels, patch_artist=True,
                    medianprops={"color": "black", "linewidth": 2})
    colors = ["#2196F3", "#4CAF50", "#FF9800", "#9C27B0", "#F44336"]
    for patch, color in zip(bp["boxes"], colors):
        patch.set_facecolor(color); patch.set_alpha(0.7)
    ax.set_title(f"RTT Distribution per Bitrate  |  Packet size = {PACKET_SIZE_B} B")
    ax.grid(axis="y", linestyle="--", alpha=0.4)
    fig.tight_layout()
    fig.savefig(os.path.join(out_dir, "plot_boxplot_bitrate.png"), dpi=150)
    plt.close(fig)

def plot_bar_comparison(df: pd.DataFrame, out_dir: str):
    stats = build_stats(df)
    bitrates = stats["bitrate_kbps"].tolist()
    x = np.arange(len(bitrates))
    owl_med = [df[df["bitrate_kbps"] == br]["OWL_ms"].median() for br in bitrates]
    owl_std = [df[df["bitrate_kbps"] == br]["OWL_ms"].std() for br in bitrates]
    fig, ax = plt.subplots(figsize=(9, 5))
    width = 0.35
    ax.bar(x - width/2, stats["median_ms"], width, yerr=stats["std_ms"],
           capsize=4, color="#2196F3", alpha=0.8, label="RTT")
    ax.bar(x + width/2, owl_med, width, yerr=owl_std,
           capsize=4, color="#4CAF50", alpha=0.8, label="One-Way Latency")
    ax.set_xticks(x)
    ax.set_xticklabels([f"{b:g} kbps" for b in bitrates])
    ax.set_ylabel("Latency (ms)")
    ax.set_title(f"RTT vs One-Way Latency per Bitrate  |  Packet size = {PACKET_SIZE_B} B")
    ax.legend()
    ax.grid(axis="y", linestyle="--", alpha=0.4)
    fig.tight_layout()
    fig.savefig(os.path.join(out_dir, "plot_bar_rtt_owl.png"), dpi=150)
    plt.close(fig)

if __name__ == "__main__":
    df = load_all_csvs(DATA_DIR)
    df = remove_outliers(df)
    os.makedirs(OUTPUT_DIR, exist_ok=True)
    plot_rtt_line(build_stats(df), OUTPUT_DIR)
    plot_owl_line(df, OUTPUT_DIR)
    plot_boxplot(df, OUTPUT_DIR)
    plot_bar_comparison(df, OUTPUT_DIR)
\end{lstlisting}

% ---- plot_latency.py --------------------------------------------------------
\begin{lstlisting}[style=appendix-py, caption={Latency vs.\ packet-size plotting}, label={lst:latency-pktsize-plot}]
"""
Latency comparison across packet sizes and bitrates.

Filename format: packet_size_<SIZE>B_<BITRATE>kb<timestamp>.csv
Columns: test_num, packet_size_B, RTT_us, one_way_us
"""

import os, re, glob
import pandas as pd
import numpy as np
import matplotlib.pyplot as plt
import matplotlib.ticker as ticker
from pathlib import Path

DATA_DIR = os.path.dirname(os.path.abspath(__file__))
OUTPUT_DIR = DATA_DIR

PACKET_SIZES = [5, 16, 32, 48, 64]
BITRATES = [9.6, 57.6, 115.2]

COLORS = {5: "#2196F3", 16: "#4CAF50", 32: "#FF9800", 48: "#9C27B0", 64: "#F44336"}
MARKERS = {9.6: "o", 57.6: "s", 115.2: "^"}
LINESTYLES = {9.6: "-", 57.6: "--", 115.2: ":"}

def parse_filename(path: str):
    name = Path(path).stem
    m = re.search(r'packet_size_(\d+)B_([\d._]+)kb', name)
    if m:
        return int(m.group(1)), float(m.group(2).replace("_", "."))
    return None

def load_all_csvs(data_dir: str):
    pattern = os.path.join(data_dir, "packet_size_*.csv")
    files = glob.glob(pattern)
    if not files:
        raise FileNotFoundError(f"No CSVs matching 'packet_size_*.csv' in {data_dir}")
    data = {}
    for f in sorted(files):
        key = parse_filename(f)
        if key is None:
            continue
        df = pd.read_csv(f)
        df.columns = ["test_num", "packet_size_B", "RTT_us", "one_way_us"]
        median_rtt = df["RTT_us"].median()
        df = df[df["RTT_us"] < 5 * median_rtt]
        data[key] = df
    return data

def summary_table(data: dict):
    rows = []
    for (ps, br), df in sorted(data.items()):
        rows.append({
            "Packet size (B)": ps, "Bitrate (kbps)": br,
            "RTT mean (ms)": df["RTT_us"].mean()/1000,
            "RTT median (ms)": df["RTT_us"].median()/1000,
            "RTT std (ms)": df["RTT_us"].std()/1000,
            "OWL median (ms)": df["one_way_us"].median()/1000,
            "OWL std (ms)": df["one_way_us"].std()/1000,
        })
    return pd.DataFrame(rows)

def plot_rtt_vs_packet_size(stats: pd.DataFrame, out_dir: str):
    fig, ax = plt.subplots(figsize=(8, 5))
    for br in sorted(stats["Bitrate (kbps)"].unique()):
        sub = stats[stats["Bitrate (kbps)"] == br].sort_values("Packet size (B)")
        ax.plot(sub["Packet size (B)"], sub["RTT median (ms)"],
                marker=MARKERS[br], linestyle=LINESTYLES[br],
                linewidth=1.8, markersize=7, label=f"{br} kbps")
        ax.fill_between(sub["Packet size (B)"],
                        sub["RTT median (ms)"] - sub["RTT std (ms)"],
                        sub["RTT median (ms)"] + sub["RTT std (ms)"], alpha=0.10)
    ax.set_xlabel("Packet Size (bytes)")
    ax.set_ylabel("Median RTT (ms)")
    ax.set_title("Round-Trip Time vs Packet Size")
    ax.set_xticks(PACKET_SIZES)
    ax.legend(title="Bitrate")
    ax.grid(True, linestyle="--", alpha=0.4)
    fig.tight_layout()
    fig.savefig(os.path.join(out_dir, "plot_rtt_vs_packet_size.png"), dpi=150)
    plt.close(fig)

def plot_owl_vs_packet_size(stats: pd.DataFrame, out_dir: str):
    fig, ax = plt.subplots(figsize=(8, 5))
    for br in sorted(stats["Bitrate (kbps)"].unique()):
        sub = stats[stats["Bitrate (kbps)"] == br].sort_values("Packet size (B)")
        ax.plot(sub["Packet size (B)"], sub["OWL median (ms)"],
                marker=MARKERS[br], linestyle=LINESTYLES[br],
                linewidth=1.8, markersize=7, label=f"{br} kbps")
        ax.fill_between(sub["Packet size (B)"],
                        sub["OWL median (ms)"] - sub["OWL std (ms)"],
                        sub["OWL median (ms)"] + sub["OWL std (ms)"], alpha=0.10)
    ax.set_xlabel("Packet Size (bytes)")
    ax.set_ylabel("Median One-Way Latency (ms)")
    ax.set_title("One-Way Latency vs Packet Size")
    ax.set_xticks(PACKET_SIZES)
    ax.legend(title="Bitrate")
    ax.grid(True, linestyle="--", alpha=0.4)
    fig.tight_layout()
    fig.savefig(os.path.join(out_dir, "plot_owl_vs_packet_size.png"), dpi=150)
    plt.close(fig)

def plot_grouped_bar(stats: pd.DataFrame, out_dir: str):
    bitrates = sorted(stats["Bitrate (kbps)"].unique())
    packet_sizes = sorted(stats["Packet size (B)"].unique())
    n_br, n_ps = len(bitrates), len(packet_sizes)
    x = np.arange(n_ps)
    width = 0.7 / n_br
    offsets = np.linspace(-(n_br-1)/2, (n_br-1)/2, n_br) * width
    fig, axes = plt.subplots(1, 2, figsize=(13, 5))
    for ax, metric, ylabel in [
        (axes[0], "RTT median (ms)", "Median RTT (ms)"),
        (axes[1], "OWL median (ms)", "Median One-Way Latency (ms)"),
    ]:
        for i, br in enumerate(bitrates):
            sub = stats[stats["Bitrate (kbps)"] == br].sort_values("Packet size (B)")
            vals = [sub[sub["Packet size (B)"] == ps][metric].values[0]
                    if len(sub[sub["Packet size (B)"] == ps]) else 0 for ps in packet_sizes]
            std_col = metric.replace("median", "std")
            errs = [sub[sub["Packet size (B)"] == ps][std_col].values[0]
                    if len(sub[sub["Packet size (B)"] == ps]) else 0 for ps in packet_sizes]
            ax.bar(x + offsets[i], vals, width, yerr=errs, label=f"{br} kbps", capsize=3)
        ax.set_xlabel("Packet Size (bytes)")
        ax.set_ylabel(ylabel)
        ax.set_xticks(x)
        ax.set_xticklabels([f"{ps} B" for ps in packet_sizes])
        ax.legend(title="Bitrate")
        ax.grid(axis="y", linestyle="--", alpha=0.4)
    fig.suptitle("Latency Comparison -- All Packet Sizes and Bitrates")
    fig.tight_layout()
    fig.savefig(os.path.join(out_dir, "plot_grouped_bar.png"), dpi=150)
    plt.close(fig)

def plot_boxplot(data: dict, out_dir: str):
    bitrates = sorted({k[1] for k in data})
    packet_sizes = sorted({k[0] for k in data})
    fig, axes = plt.subplots(1, len(bitrates), figsize=(5*len(bitrates), 5), sharey=True)
    if len(bitrates) == 1:
        axes = [axes]
    for ax, br in zip(axes, bitrates):
        groups = [data[(ps, br)]["RTT_us"].values/1000 for ps in packet_sizes if (ps, br) in data]
        labels = [f"{ps} B" for ps in packet_sizes if (ps, br) in data]
        bp = ax.boxplot(groups, labels=labels, patch_artist=True,
                        medianprops={"color": "black", "linewidth": 2})
        for patch, ps in zip(bp["boxes"], [ps for ps in packet_sizes if (ps, br) in data]):
            patch.set_facecolor(COLORS.get(ps, "#888")); patch.set_alpha(0.75)
        ax.set_title(f"{br} kbps")
        ax.grid(axis="y", linestyle="--", alpha=0.4)
    axes[0].set_ylabel("RTT (ms)")
    fig.suptitle("RTT Distribution -- Grouped by Bitrate")
    fig.tight_layout()
    fig.savefig(os.path.join(out_dir, "plot_boxplot_rtt.png"), dpi=150)
    plt.close(fig)

def plot_heatmap(stats: pd.DataFrame, out_dir: str):
    import matplotlib.colors as mcolors
    for metric, title, fname in [
        ("RTT median (ms)", "Median RTT (ms)", "plot_heatmap_rtt.png"),
        ("OWL median (ms)", "Median One-Way Latency (ms)", "plot_heatmap_owl.png"),
    ]:
        pivot = stats.pivot(index="Packet size (B)", columns="Bitrate (kbps)", values=metric)
        fig, ax = plt.subplots(figsize=(6, 4))
        im = ax.imshow(pivot.values, aspect="auto", cmap="YlOrRd",
                       norm=mcolors.Normalize(vmin=pivot.values.min(), vmax=pivot.values.max()))
        ax.set_xticks(range(len(pivot.columns)))
        ax.set_xticklabels([f"{c} kbps" for c in pivot.columns])
        ax.set_yticks(range(len(pivot.index)))
        ax.set_yticklabels([f"{r} B" for r in pivot.index])
        ax.set_title(f"Heatmap -- {title}")
        for i in range(len(pivot.index)):
            for j in range(len(pivot.columns)):
                val = pivot.values[i, j]
                if not np.isnan(val):
                    ax.text(j, i, f"{val:.2f}", ha="center", va="center", fontsize=9,
                            color="white" if val > pivot.values.max()*0.65 else "black")
        plt.colorbar(im, ax=ax, label=title)
        fig.tight_layout()
        fig.savefig(os.path.join(out_dir, fname), dpi=150)
        plt.close(fig)

if __name__ == "__main__":
    data = load_all_csvs(DATA_DIR)
    stats = summary_table(data)
    os.makedirs(OUTPUT_DIR, exist_ok=True)
    plot_rtt_vs_packet_size(stats, OUTPUT_DIR)
    plot_owl_vs_packet_size(stats, OUTPUT_DIR)
    plot_grouped_bar(stats, OUTPUT_DIR)
    plot_boxplot(data, OUTPUT_DIR)
    plot_heatmap(stats, OUTPUT_DIR)
\end{lstlisting}

\endinput

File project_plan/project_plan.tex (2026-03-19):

\documentclass[a4paper,12pt]{article}
\usepackage[utf8]{inputenc}
\usepackage[T1]{fontenc}
\usepackage[margin=2.5cm]{geometry}
\usepackage{graphicx}
\usepackage{hyperref}
\usepackage{lastpage}
\usepackage{fancyhdr}
\usepackage{datetime}

% Danish language support
\usepackage[danish]{babel}

% Custom commands
\newcommand{\projectID}{107210}
\newcommand{\studentName}{August Binner Becktor}
\newcommand{\studentID}{234396}
\newcommand{\supervisor}{Jens Christian Andersen, jcan@dtu.dk}
\newcommand{\projectDate}{\today}
\newcommand{\duration}{Feb 2 - Jun 8, 2026 (18 weeks)}
\newcommand{\ECTS}{20}

% Title page
\begin{document}

\begin{titlepage}
    \centering
    \vspace*{2cm}
    
    \textbf{DANMARKS TEKNISKE UNIVERSITET} \\
    \textit{Institute of Electrical and Photonic Engineering} \\
    \vspace{2cm}
    
    \textbf{BACHELOR PROJECT PLAN} \\
    \vspace{1cm}
    
    \hrule
    \vspace{1cm}
    
    {\Large\textbf{\projectID}} \\
    \vspace{0.5cm}
    \textit{Design of long-range safety control for autonomous robots} \\
    \hrule
    
    \vspace{2cm}
    
    \begin{tabular}{ll}
        \textbf{Student:} & \studentName \\
        \textbf{Student ID:} & \studentID \\
        \textbf{Supervisor:} & \supervisor \\
        \textbf{Date:} & \projectDate \\
        \textbf{Duration:} & \duration \\
        \textbf{ECTS:} & \ECTS
    \end{tabular}
    
    \vspace{3cm}
    
    \textit{Department of Electrical and Photonic Engineering} \\
    \textit{DTU Space} \\
    \textit{Technical University of Denmark}
    
\end{titlepage}

% Table of contents
\newpage
\tableofcontents
\newpage

% Content sections
\section{Project Description}
\input{sections/description}

\section{Project Scope}
\input{sections/scope}

\section{Problem Analysis}
\input{sections/problem}

\section{Objectives}
\input{sections/objectives}

\section{Deliverables}
\input{sections/deliverables}

\section{Methodology}
\input{sections/methodology}

\section{Time Schedule}
\input{sections/schedule}

\section{Risk Assessment}
\input{sections/risks}

% References
\newpage
\section{References}
\begin{thebibliography}{99}
    \bibitem{dtu} DTU - Technical University of Denmark. \textit{Department of Electrical and Photonic Engineering}. Available at: \url{https://www.dtu.dk/english/education/undergraduate/b-eng-and-bsc-in-engineering}
    \bibitem{project} DTU Project Database. Project ID: \projectID.
\end{thebibliography}

% Appendices
\newpage
\appendix
\section{Appendix A: Supervisor Confirmation}
\textit{To be signed by supervisor}

\vspace{2cm}
\noindent
\begin{tabular}{p{7cm}p{7cm}}
    \textbf{Supervisor signature:} & \textbf{Date:} \\
    & \\
    \hline
    \textit{Line for signature} & \\
\end{tabular}

\end{document}

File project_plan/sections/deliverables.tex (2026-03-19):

The following deliverables are expected from this project:

\subsection*{Hardware Deliverables}
\begin{enumerate}
    \item \textbf{Remote Controller Unit}
    \begin{itemize}
        \item Custom PCB with microcontroller, radio transceiver, joystick controls, and OLED display
        \item 3D-printed enclosure
        \item Battery management system (8+ hour runtime)
    \end{itemize}
    
    \item \textbf{Robot Receiver Unit}
    \begin{itemize}
        \item Custom PCB with microcontroller, radio transceiver, and motor control interface
        \item 3D-printed enclosure
        \item Power management for robot-side operation
    \end{itemize}
    
    \item \textbf{Circuit Diagrams and PCB Layouts}
    \begin{itemize}
        \item Complete schematics for both units
        \item Gerber files for PCB manufacturing
        \item Bill of materials (BOM)
    \end{itemize}
\end{enumerate}

\subsection*{Software Deliverables}
\begin{enumerate}
    \item \textbf{Firmware for Remote Unit}
    \begin{itemize}
        \item Joystick input processing
        \item Radio communication protocol
        \item OLED display driver
        \item Battery monitoring
    \end{itemize}
    
    \item \textbf{Firmware for Robot Unit}
    \begin{itemize}
        \item Radio communication handler
        \item Motor control interface
        \item Communication loss detection
        \item Safety shutdown logic
    \end{itemize}
\end{enumerate}

\subsection*{Documentation Deliverables}
\begin{enumerate}
    \item \textbf{Technical Report} (Bachelor thesis, approx. 40-60 pages)
    \item \textbf{User Manual} describing operation of the system
    \item \textbf{Test Report} documenting validation results
    \item \textbf{Source Code} (documented and version-controlled)
\end{enumerate}

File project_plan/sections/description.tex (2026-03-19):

\subsection*{English}
For outdoor autonomous mobile robots, the current solution relying on a gamepad is too limited. This project aims to develop a long-range wireless remote control system with safety features for autonomous robots. The system must detect loss of communication and cut power to motors, allow manual override of velocity and turn rate, and operate for at least 8 hours on battery. Optionally, the remote should display messages from the robot such as battery status.

The project involves circuit and PCB design, as well as 3D-printed casing for the devices.

\subsection*{Dansk}
For autonome mobile udendørs robotter er den nuværende løsning med en gamepad for begrænset. Dette projekt har til formål at udvikle et langtrækkende trådløst fjernbetjeningssystem med sikkerhedsfunktioner til autonome robotter. Systemet skal detektere tab af kommunikation og slukke for strømmen til motorerne, tillade manuel overstyring af hastighed og svinghastighed og fungere i mindst 8 timer på batteri. Fjernbetjeningen skal eventuelt vise beskeder fra robotten, såsom batteristatus.

Projektet involverer kredsløbs- og PCB-design samt 3D-printet kabinet til enhederne.

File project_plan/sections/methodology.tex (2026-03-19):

The project will follow a structured engineering design methodology:

\subsection*{Phase 1: Research and Planning (Weeks 1-3)}
\begin{itemize}
    \item Literature review of wireless communication protocols (LoRa, RFM69, etc.)
    \item Market analysis of existing remote control solutions
    \item Component selection and evaluation
    \item Initial system architecture design
\end{itemize}

\subsection*{Phase 2: Design (Weeks 4-8)}
\begin{itemize}
    \item Circuit design for remote and robot units
    \item PCB layout and routing
    \item 3D enclosure design (CAD)
    \item Communication protocol definition
    \item Firmware architecture planning
\end{itemize}

\subsection*{Phase 3: Implementation (Weeks 9-13)}
\begin{itemize}
    \item PCB fabrication and assembly
    \item 3D printing of enclosures
    \item Firmware development and testing
    \item Integration testing
\end{itemize}

\subsection*{Phase 4: Testing and Validation (Weeks 14-16)}
\begin{itemize}
    \item Range testing
    \item Safety feature validation
    \item Battery life testing
    \item Performance optimization
\end{itemize}

\subsection*{Phase 5: Documentation (Weeks 17-18)}
\begin{itemize}
    \item Technical report writing
    \item User manual creation
    \item Final presentation preparation
\end{itemize}

\subsection*{Development Approach}
\begin{itemize}
    \item \textbf{Version Control:} Git for source code and documentation
    \item \textbf{Prototyping:} Breadboard testing before PCB design
    \item \textbf{Testing:} Iterative testing throughout development
    \item \textbf{Documentation:} Continuous documentation of design decisions
\end{itemize}

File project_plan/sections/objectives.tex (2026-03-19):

The project objectives are divided into primary and secondary objectives:

\subsection*{Primary Objectives}
\begin{enumerate}
    \item \textbf{Design a long-range wireless communication system} using the 433 MHz band with a minimum range of 500 meters.
    
    \item \textbf{Implement safety shutdown mechanism} that cuts power to robot motors within 100 ms of communication loss detection.
    
    \item \textbf{Develop manual override functionality} allowing the operator to control velocity (forward/reverse) and turn rate (left/right).
    
    \item \textbf{Design battery-powered remote} with minimum 8-hour operation time.
    
    \item \textbf{Design and build custom PCB} for both remote and robot units.
    
    \item \textbf{Design and 3D-print enclosures} for both devices.
\end{enumerate}

\subsection*{Secondary Objectives (Optional)}
\begin{enumerate}
    \item \textbf{Implement bidirectional communication} to display robot status (battery voltage, errors) on the remote.
    
    \item \textbf{Add low battery warning} to the remote display.
    
    \item \textbf{Implement signal strength indicator} (RSSI) on the remote.
\end{enumerate}

\subsection*{Success Criteria}
The project will be considered successful if:
\begin{itemize}
    \item Communication range exceeds 500 meters in open terrain
    \item Motor shutdown occurs within 100 ms of signal loss
    \item Remote operates for minimum 8 hours on a full battery charge
    \item Both units are fully functional prototypes with custom PCBs and enclosures
\end{itemize}

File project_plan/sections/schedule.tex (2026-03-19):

The project spans 18 weeks from February 2, 2026 to June 8, 2026. The following table summarizes the time allocation:

\begin{table}[h]
\centering
\begin{tabular}{|l|c|c|c|}
\hline
\textbf{Phase} & \textbf{Description} & \textbf{Weeks} & \textbf{Duration} \\
\hline
1 & Research and Planning & 1-3 & 3 weeks \\
\hline
2 & Design & 4-8 & 5 weeks \\
\hline
3 & Implementation & 9-13 & 5 weeks \\
\hline
4 & Testing and Validation & 14-16 & 3 weeks \\
\hline
5 & Documentation & 17-18 & 2 weeks \\
\hline
\end{tabular}
\caption{Project Phase Overview}
\end{table}

\subsection*{Detailed Schedule}

\begin{table}[h]
\centering
\begin{tabular}{|l|c|l|}
\hline
\textbf{Task} & \textbf{Week} & \textbf{Deliverable} \\
\hline
Literature Review & 1-2 & Research summary \\
\hline
Component Selection & 2-3 & Component shortlist, initial budget \\
\hline
System Architecture & 3 & System design document \\
\hline
Circuit Design & 4-5 & Schematics complete \\
\hline
PCB Layout & 5-6 & Gerber files submitted \\
\hline
Enclosure Design & 6-7 & 3D models complete \\
\hline
Firmware Development & 7-11 & Source code modules \\
\hline
PCB Assembly & 8-9 & Assembled boards \\
\hline
Enclosure Printing & 10-11 & Printed enclosures \\
\hline
Integration Testing & 12-13 & Working prototype \\
\hline
Range Testing & 14 & Test report \\
\hline
Safety Validation & 14-15 & Safety test results \\
\hline
Report Writing & 16-18 & Draft and final thesis \\
\hline
Final Presentation & 18 & Presentation slides \\
\hline
\end{tabular}
\caption{Detailed Task Schedule}
\end{table}

\begin{figure}[h]
\centering
\textbf{[Insert Gantt Chart Here]}
\caption{Project Gantt Chart}
\end{figure}

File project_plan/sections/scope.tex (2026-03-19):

The project scope includes the following requirements:

\begin{enumerate}
    \item \textbf{Communication Loss Detection:} System must detect when communication is lost and immediately cut power to the robot's motors.
    
    \item \textbf{Manual Control Override:} The remote must allow the operator to take over control of the vehicle, controlling drive velocity and turn rate.
    
    \item \textbf{Power Supply - Robot Side:} The mobile robot shall power the on-board receiver/control unit.
    
    \item \textbf{Power Supply - Remote Side:} The hand-held remote shall be battery powered with at least 8 hours of operation on a fully charged battery.
    
    \item \textbf{Status Display (Optional):} The remote end should be able to display messages from the robot, e.g., remaining battery power.
    
    \item \textbf{Communication Frequency:} The system shall use the 433 MHz band for communication.
    
    \item \textbf{Hardware Development:} The project shall include circuit and PCB design for both the remote and robot units.
    
    \item \textbf{Enclosure Design:} 3D-printed casing shall be designed and produced for both devices.
\end{enumerate}

\subsection*{Out of Scope}
\begin{itemize}
    \item Development of the autonomous navigation algorithms
    \item Integration with existing robot control systems (beyond motor power control)
    \item Production of multiple units beyond the prototype
    \item Regulatory certification (CE, FCC, etc.)
\end{itemize}

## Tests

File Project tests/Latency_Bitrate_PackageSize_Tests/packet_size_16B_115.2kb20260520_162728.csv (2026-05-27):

Sample | PacketSize_Bytes | RTT_us | OneWayLatency_ms
1 | 16 | 4665 | 2.332
2 | 16 | 4788 | 2.394
3 | 16 | 4778 | 2.389
4 | 16 | 4781 | 2.391
5 | 16 | 4789 | 2.395
6 | 16 | 4785 | 2.392
7 | 16 | 4782 | 2.391
8 | 16 | 150760 | 75.38
9 | 16 | 4791 | 2.395
10 | 16 | 4776 | 2.388
11 | 16 | 4793 | 2.397
12 | 16 | 4798 | 2.399
13 | 16 | 4789 | 2.395
14 | 16 | 4789 | 2.395
15 | 16 | 4775 | 2.388
16 | 16 | 4788 | 2.394
17 | 16 | 4797 | 2.398
18 | 16 | 4778 | 2.389
19 | 16 | 4795 | 2.398
20 | 16 | 4783 | 2.391
21 | 16 | 4797 | 2.398
22 | 16 | 4784 | 2.392
23 | 16 | 4783 | 2.391
24 | 16 | 4790 | 2.395
25 | 16 | 4804 | 2.402
26 | 16 | 4778 | 2.389
27 | 16 | 4773 | 2.386
28 | 16 | 4791 | 2.395
29 | 16 | 4779 | 2.389
30 | 16 | 4787 | 2.394
31 | 16 | 4775 | 2.388
32 | 16 | 4806 | 2.403
33 | 16 | 4799 | 2.399
34 | 16 | 4789 | 2.395
35 | 16 | 4789 | 2.395
36 | 16 | 4797 | 2.398
37 | 16 | 4801 | 2.401
38 | 16 | 4799 | 2.399
39 | 16 | 4802 | 2.401
40 | 16 | 4797 | 2.398
41 | 16 | 4786 | 2.393
42 | 16 | 4800 | 2.4
43 | 16 | 4781 | 2.391
44 | 16 | 4782 | 2.391
45 | 16 | 4784 | 2.392
46 | 16 | 4801 | 2.401
47 | 16 | 4802 | 2.401
48 | 16 | 4791 | 2.395
49 | 16 | 4773 | 2.386
50 | 16 | 4780 | 2.39
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

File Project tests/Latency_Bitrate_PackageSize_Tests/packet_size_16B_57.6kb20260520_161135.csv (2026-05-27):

Sample | PacketSize_Bytes | RTT_us | OneWayLatency_ms
1 | 16 | 7669 | 3.835
2 | 16 | 31642 | 15.821
3 | 16 | 7828 | 3.914
4 | 16 | 7819 | 3.909
5 | 16 | 7829 | 3.914
6 | 16 | 7838 | 3.919
7 | 16 | 7819 | 3.909
8 | 16 | 7840 | 3.92
9 | 16 | 7821 | 3.911
10 | 16 | 7839 | 3.92
11 | 16 | 7816 | 3.908
12 | 16 | 7839 | 3.92
13 | 16 | 7811 | 3.905
14 | 16 | 7822 | 3.911
15 | 16 | 7839 | 3.92
16 | 16 | 7827 | 3.914
17 | 16 | 7821 | 3.911
18 | 16 | 7821 | 3.911
19 | 16 | 7839 | 3.92
20 | 16 | 7824 | 3.912
21 | 16 | 76344 | 38.172
22 | 16 | 7847 | 3.924
23 | 16 | 7839 | 3.92
24 | 16 | 7828 | 3.914
25 | 16 | 7825 | 3.912
26 | 16 | 7820 | 3.91
27 | 16 | 7829 | 3.914
28 | 16 | 7825 | 3.912
29 | 16 | 7837 | 3.918
30 | 16 | 7821 | 3.911
31 | 16 | 7830 | 3.915
32 | 16 | 7828 | 3.914
33 | 16 | 7840 | 3.92
34 | 16 | 7831 | 3.915
35 | 16 | 7830 | 3.915
36 | 16 | 7832 | 3.916
37 | 16 | 7841 | 3.921
38 | 16 | 7831 | 3.915
39 | 16 | 7819 | 3.909
40 | 16 | 7828 | 3.914
41 | 16 | 7818 | 3.909
42 | 16 | 7835 | 3.918
43 | 16 | 7821 | 3.911
44 | 16 | 7839 | 3.92
45 | 16 | 7827 | 3.914
46 | 16 | 7845 | 3.922
47 | 16 | 7827 | 3.914
48 | 16 | 7829 | 3.914
49 | 16 | 7824 | 3.912
50 | 16 | 7831 | 3.915
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

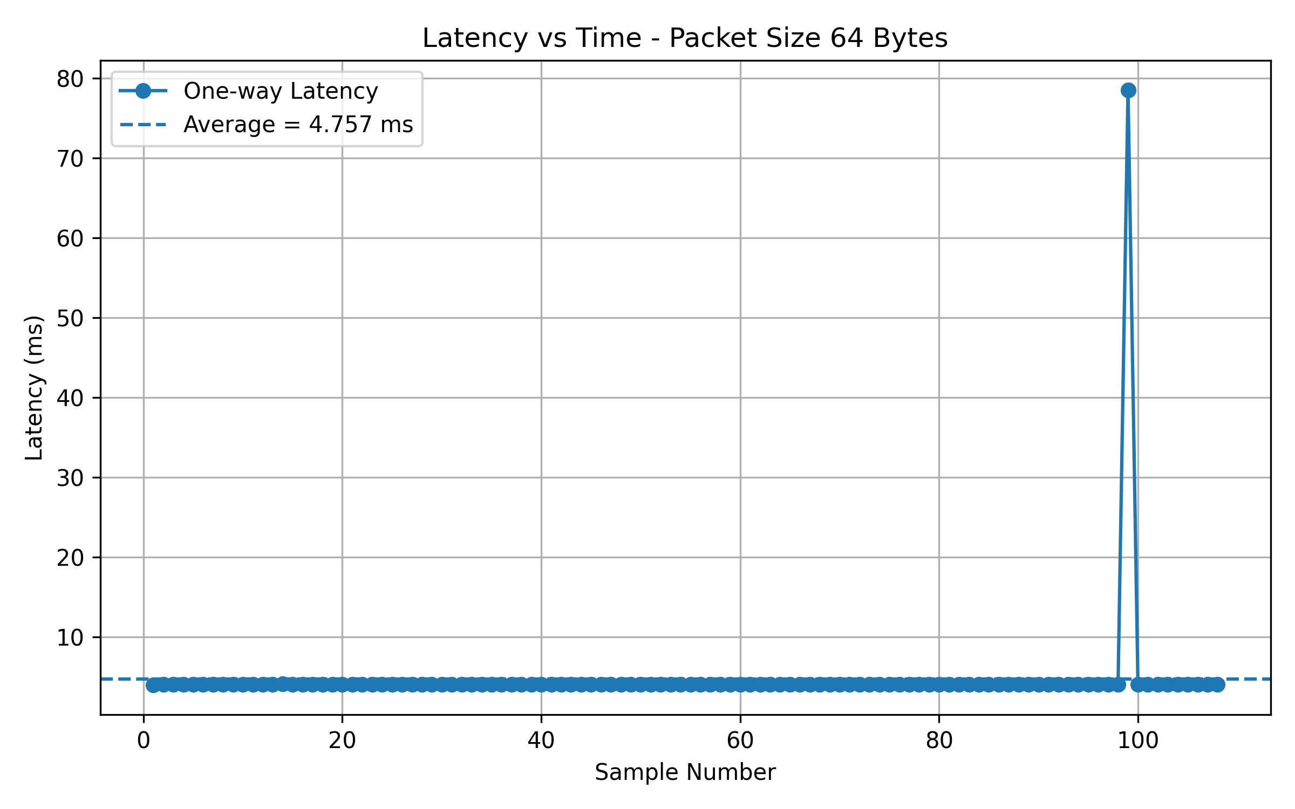
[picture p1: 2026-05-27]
Project tests/Latency_Bitrate_PackageSize_Tests/packet_size_64B_115.2kb20260520_162340.png

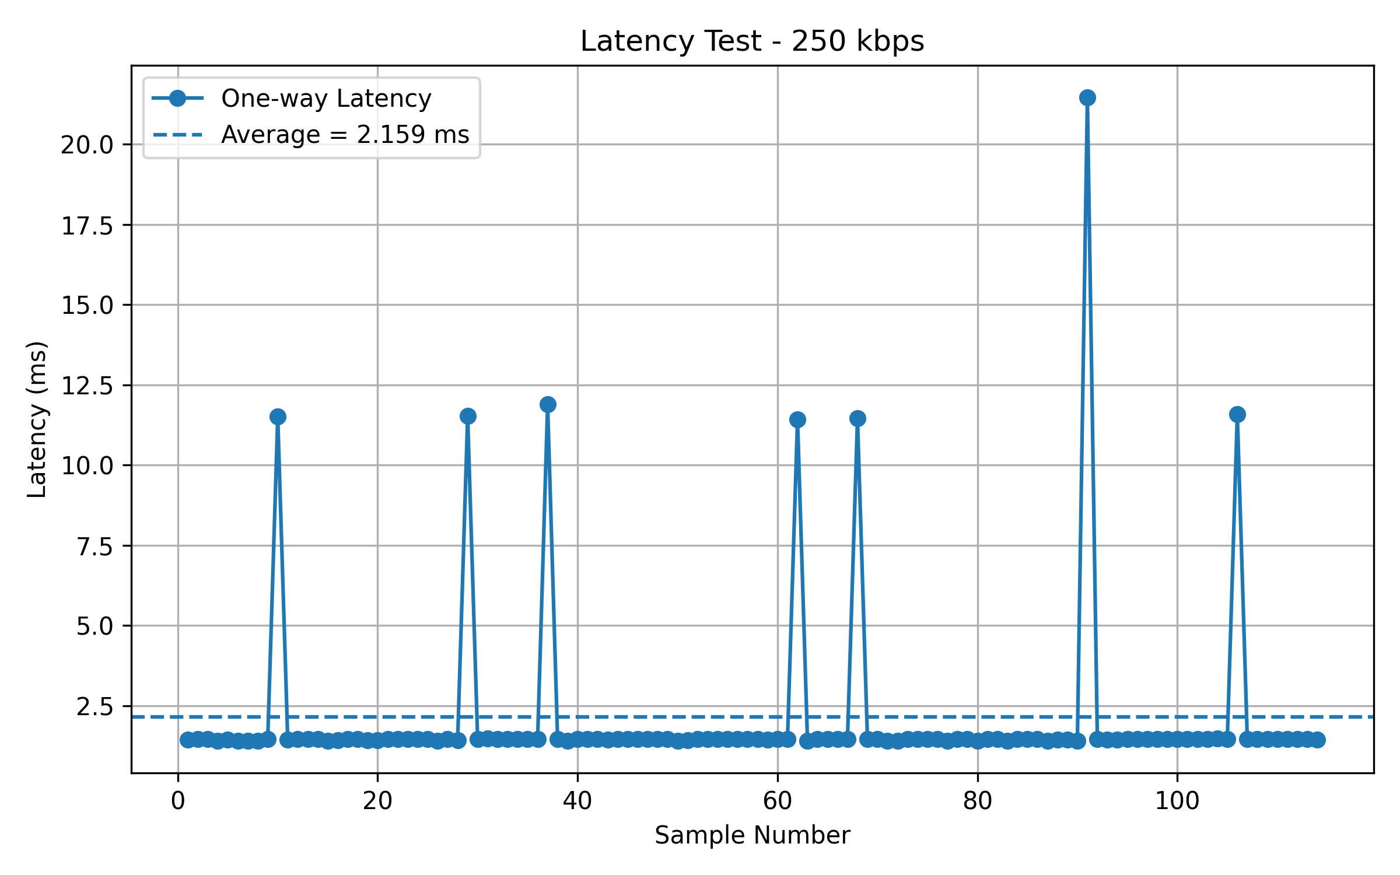
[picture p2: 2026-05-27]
Project tests/latency_Bitrate_test/latency_250_kbps_20260520_151243.png

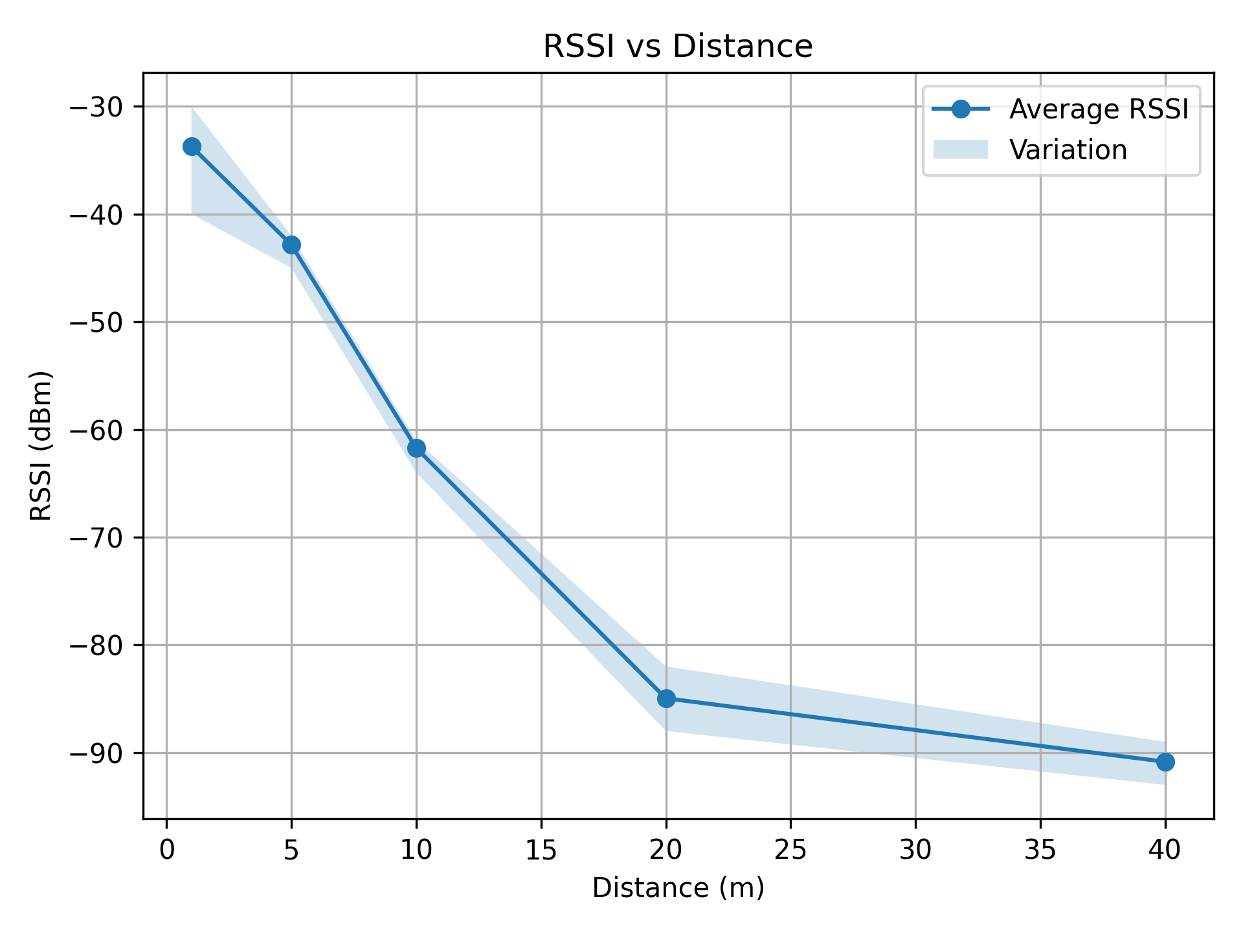
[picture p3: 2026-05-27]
Project tests/RSSI_Antenna_test/rssi_plot_Horizontal_16.7cm_20260521_132743.png

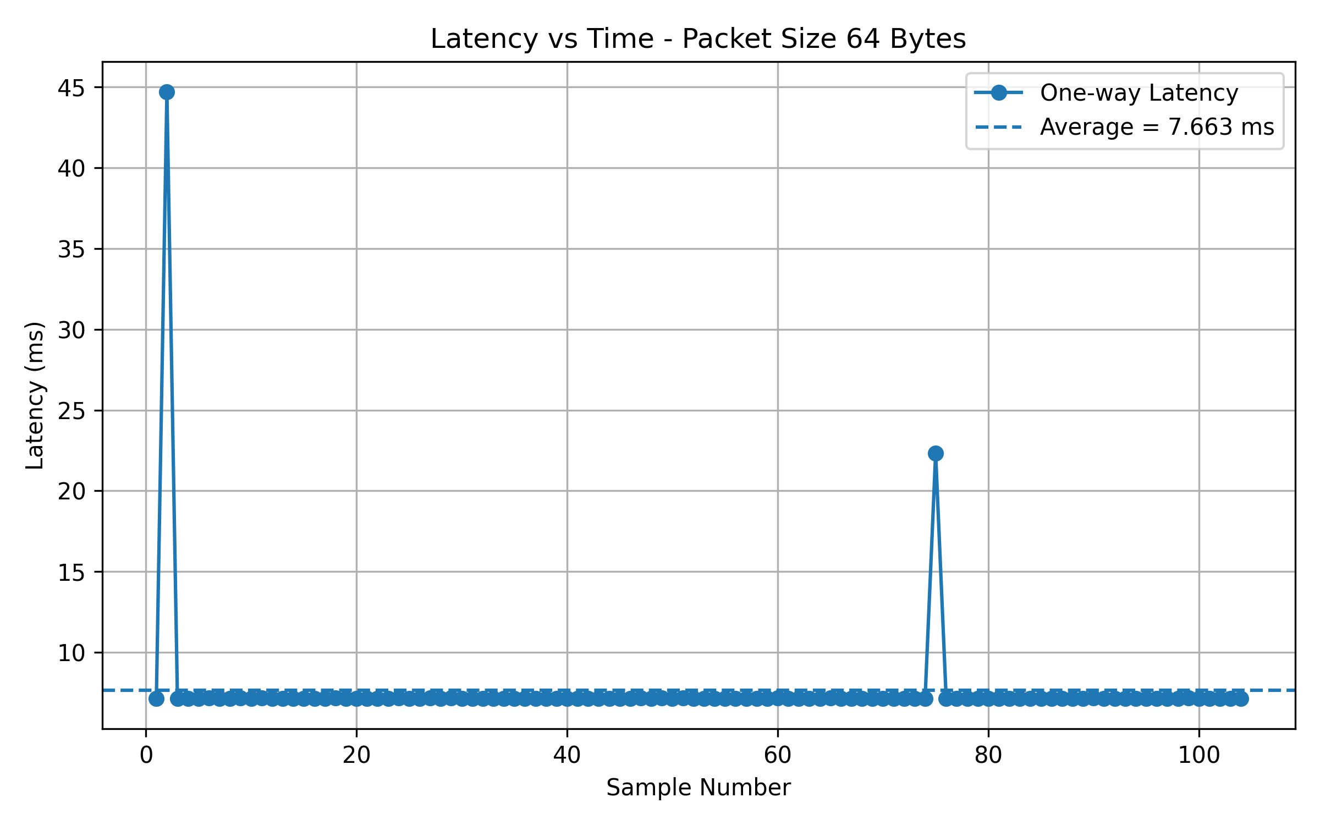
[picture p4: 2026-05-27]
Project tests/Latency_Bitrate_PackageSize_Tests/packet_size_64B_57.6kb20260520_160848.png

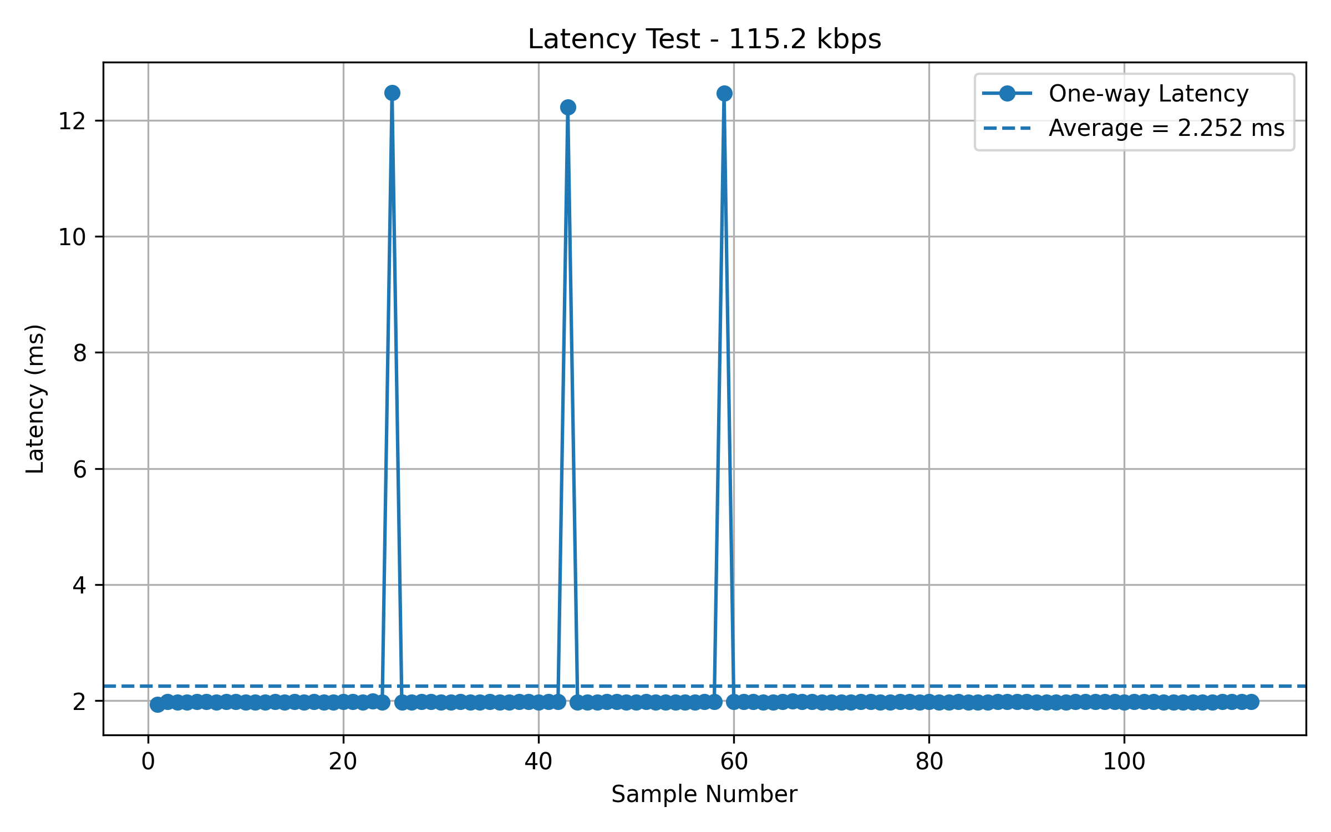
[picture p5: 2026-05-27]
Project tests/latency_Bitrate_test/latency_115.2_kbps_20260520_150932.png

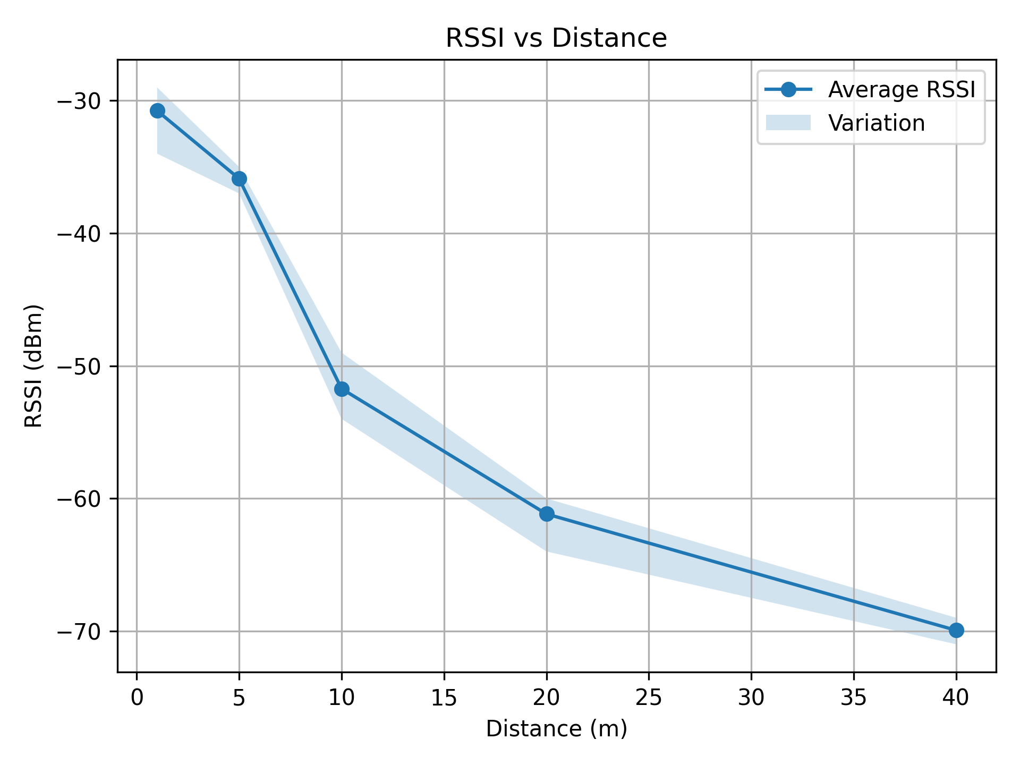
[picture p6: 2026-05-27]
Project tests/RSSI_Antenna_test/rssi_plot_Horizontal_17.1cm_20260521_123817.png

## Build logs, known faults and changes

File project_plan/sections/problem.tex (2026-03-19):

Current remote control solutions for outdoor autonomous mobile robots rely on gamepad controllers, which present several limitations:

\subsection*{Limitations of Current Solution}
\begin{itemize}
    \item \textbf{Limited Range:} Standard gamepads using Bluetooth or 2.4 GHz wireless have very limited range (typically 10-30 meters), insufficient for outdoor operations.
    
    \item \textbf{No Safety Features:} Consumer-grade gamepads lack built-in safety mechanisms for communication loss detection.
    
    \item \textbf{Power Consumption:} Gamepads typically have short battery life, unsuitable for extended outdoor deployments.
    
    \item \textbf{No Feedback:} Standard gamepads cannot receive data from the robot (battery status, errors, etc.).
    
    \item \textbf{Noisy Environments:} 2.4 GHz band is crowded and susceptible to interference.
\end{itemize}

\subsection*{Problem Statement}
The current gamepad-based control system is inadequate for outdoor autonomous mobile robots that require:
\begin{itemize}
    \item Long-range reliable communication
    \item Automatic safety shutdown on communication loss
    \item Extended battery life (8+ hours)
    \item Bidirectional communication for status updates
\end{itemize}

This project addresses these limitations by designing a custom long-range remote control system with safety features.

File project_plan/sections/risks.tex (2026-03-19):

Risk assessment identifies potential issues and mitigation strategies:

\begin{table}[h]
\centering
\begin{tabular}{|p{3cm}|p{4cm}|p{4cm}|p{2cm}|}
\hline
\textbf{Risk} & \textbf{Description} & \textbf{Mitigation} & \textbf{Impact} \\
\hline
PCB Manufacturing Delays & PCB fabrication takes longer than expected & Order PCBs early; have breadboard backup & High \\
\hline
Component Availability & Key components out of stock & Order all components at start of design phase & High \\
\hline
Range Insufficient & Communication range below 500m & Use higher gain antennas; optimize protocol & Medium \\
\hline
Battery Life Below Target & Remote doesn't achieve 8-hour runtime & Optimize firmware; use larger battery & Medium \\
\hline
Safety Feature Failure & Motor cutoff doesn't work reliably & Redundant safety systems; extensive testing & High \\
\hline
Schedule Overrun & Tasks take longer than planned & Build in buffer time; prioritize critical tasks & Medium \\
\hline
Firmware Bugs & Software issues cause system failures & Extensive testing; modular development & Medium \\
\hline
3D Print Failures & Enclosure prints fail or don't fit & Multiple prototypes; adjustable design & Low \\
\hline
\end{tabular}
\caption{Risk Assessment Matrix}
\end{table}

\subsection*{Contingency Plans}

\begin{enumerate}
    \item \textbf{If PCBs are delayed:} Use breadboard/wire-wrap prototypes to continue firmware development
    \item \textbf{If range is insufficient:} Implement range extender techniques (higher antenna, lower data rate)
    \item \textbf{If battery life is insufficient:} Switch to larger battery pack; implement power-saving modes
    \item \textbf{If safety feature fails testing:} Add redundant microcontroller watchdog; implement failsafe modes
\end{enumerate}

\subsection*{Project Risks - Priority Actions}
\begin{itemize}
    \item \textbf{Priority 1:} Ensure safety shutdown mechanism is thoroughly tested
    \item \textbf{Priority 2:} Verify 500m range capability early in testing phase
    \item \textbf{Priority 3:} Complete PCB design with sufficient time for manufacturing
\end{itemize}

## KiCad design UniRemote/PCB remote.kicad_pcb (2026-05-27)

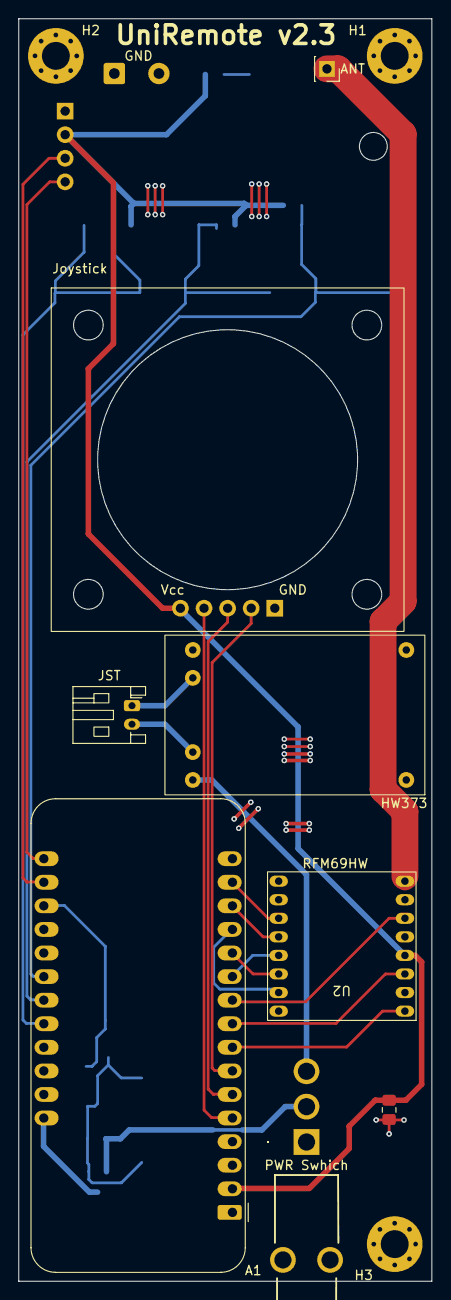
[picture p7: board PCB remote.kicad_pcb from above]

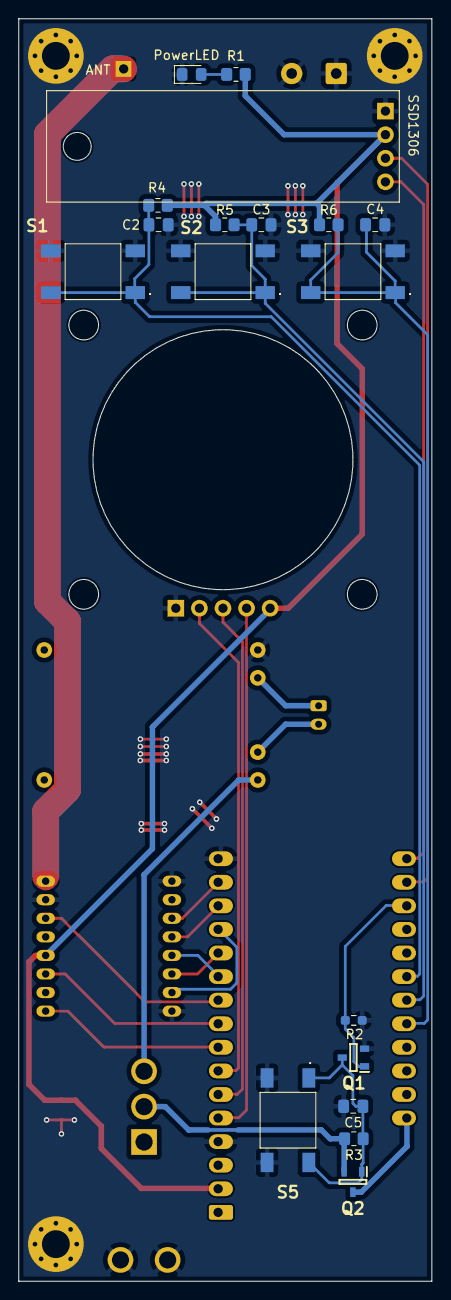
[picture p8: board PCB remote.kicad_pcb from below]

Board: 2 copper layers, 44.5 x 136.0 mm, 30 parts (18 on the bottom side), 27 nets.

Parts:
A1: Adafruit_Feather_M0_Adalogger; Adafruit_Feather
ANT: Conn_01x01; PinSocket_1x01_P2.54mm_Vertical
C1, C5: 10uF; C_0805_2012Metric_Pad1.18x1.45mm_HandSolder
C2, C3, C4: 100nF; C_0805_2012Metric_Pad1.18x1.45mm_HandSolder
D1: LED; LED_0805_2012Metric_Pad1.15x1.40mm_HandSolder
GND: Conn_01x02_Socket; SolderWire-0.5sqmm_1x02_P4.8mm_D0.9mm_OD2.3mm
H1, H2, H3: MountingHole_Pad; MountingHole_3mm_Pad_Via
HW373: HW373
JST: 02_Socket; JST_PH_S2B-PH-K_1x02_P2.00mm_Horizontal
PWR Swhich: 100SP1T1B1M7QEH; 100SP1T1B1M7QEH(redSwitch)
Q1: BSS138; nmos
Q2: PMV28XPEAR; Pmos
R1: 280; R_0805_2012Metric_Pad1.20x1.40mm_HandSolder
R2: 47k; R_0603_1608Metric_Pad0.98x0.95mm_HandSolder
R3: 220k; R_0805_2012Metric_Pad1.20x1.40mm_HandSolder
R4, R5, R6: 10k; R_0805_2012Metric_Pad1.20x1.40mm_HandSolder
S1, S2, S3, S5: TL3301TF160QG
SSD1306: SSD1306; SSD1306(128x32)
U2: RFM69HW; RFM69HCW(homemade)
U3: Joystick

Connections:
+3.3V: A1.2 (3V3), C1.2, R1.1, R4.1, R5.1, R6.1, SSD1306.2 (VCC), U2.4 (3.3V), U3.5 (VCC)
+BATT: A1.28 (VBAT), Q2.3 (D)
/B-D10-S1: A1.22 (D10), C2.1, R4.2, S1.1 (COM_1), S1.2 (COM_2)
/B-D11-S2: A1.23 (D11), C3.1, R5.2, S2.1 (COM_1), S2.2 (COM_2)
/B-D12-S3: A1.24 (D12), C4.1, R6.2, S3.1 (COM_1), S3.2 (COM_2)
/J-A0-Sel: A1.7 (A2), U3.2 (Sel)
/J-A1-Yout: A1.6 (A1), U3.3 (Yout)
/J-A2-Xout: A1.5 (DAC0/A0), U3.4 (Xout)
/P-S4-BAT: PWR Swhich.2 (COM), Q2.2 (S), R3.1
/P-USBC-S4: HW373.3 (out+), PWR Swhich.3 (NO)
/R-A3-D02: A1.8 (A3), U2.1 (DIO2)
/R-A4-DO0: A1.9 (A4), U2.3 (DIO0)
/R-A5-DO3: A1.10 (A5), U2.6 (DIO3)
/R-D0-NSS: A1.14 (RX/D0), U2.12 (NSS)
/R-D1-RT: A1.15 (TX/D1), U2.11 (RESET)
/R-D22-MISO: A1.13 (MISO/D22), U2.15 (MISO)
/R-D23-MOSI: A1.12 (MOSI/D23), U2.14 (MOSI)
/R-D24-SCK: A1.11 (SCK/D24), U2.13 (SCK)
/SCL: A1.18 (SCL/D21), SSD1306.3 (SCK)
/SDA: A1.17 (SDA/D20), SSD1306.4 (SDA)
GND: A1.4 (GND), A1.16 (GND), C1.1, C2.2, C3.2, C4.2, C5.2, D1.1 (K), GND.1, GND.2, H1.1, H2.1, H3.1, HW373.4 (out-), PWR Swhich.4 (MH1), PWR Swhich.5 (MH2), Q1.2 (S), R2.2, S1.3 (NO_1), S1.4 (NO_2), S2.3 (NO_1), S2.4 (NO_2), S3.3 (NO_1), S3.4 (NO_2), S5.3 (NO_1), S5.4 (NO_2), SSD1306.1 (GND), U2.7 (GND), U2.9 (GND), U2.16 (GND), U3.1 (GND)
unnamed: D1.2 (A), R1.2
unnamed: ANT.1, U2.8 (ANA)
unnamed: HW373.2 (b-), JST.1
unnamed: HW373.1 (b+), JST.2
unnamed: C5.1, Q1.3 (D), Q2.1 (G), R3.2, S5.1 (COM_1), S5.2 (COM_2)
PWRC: A1.19 (D5), Q1.1 (G), R2.1

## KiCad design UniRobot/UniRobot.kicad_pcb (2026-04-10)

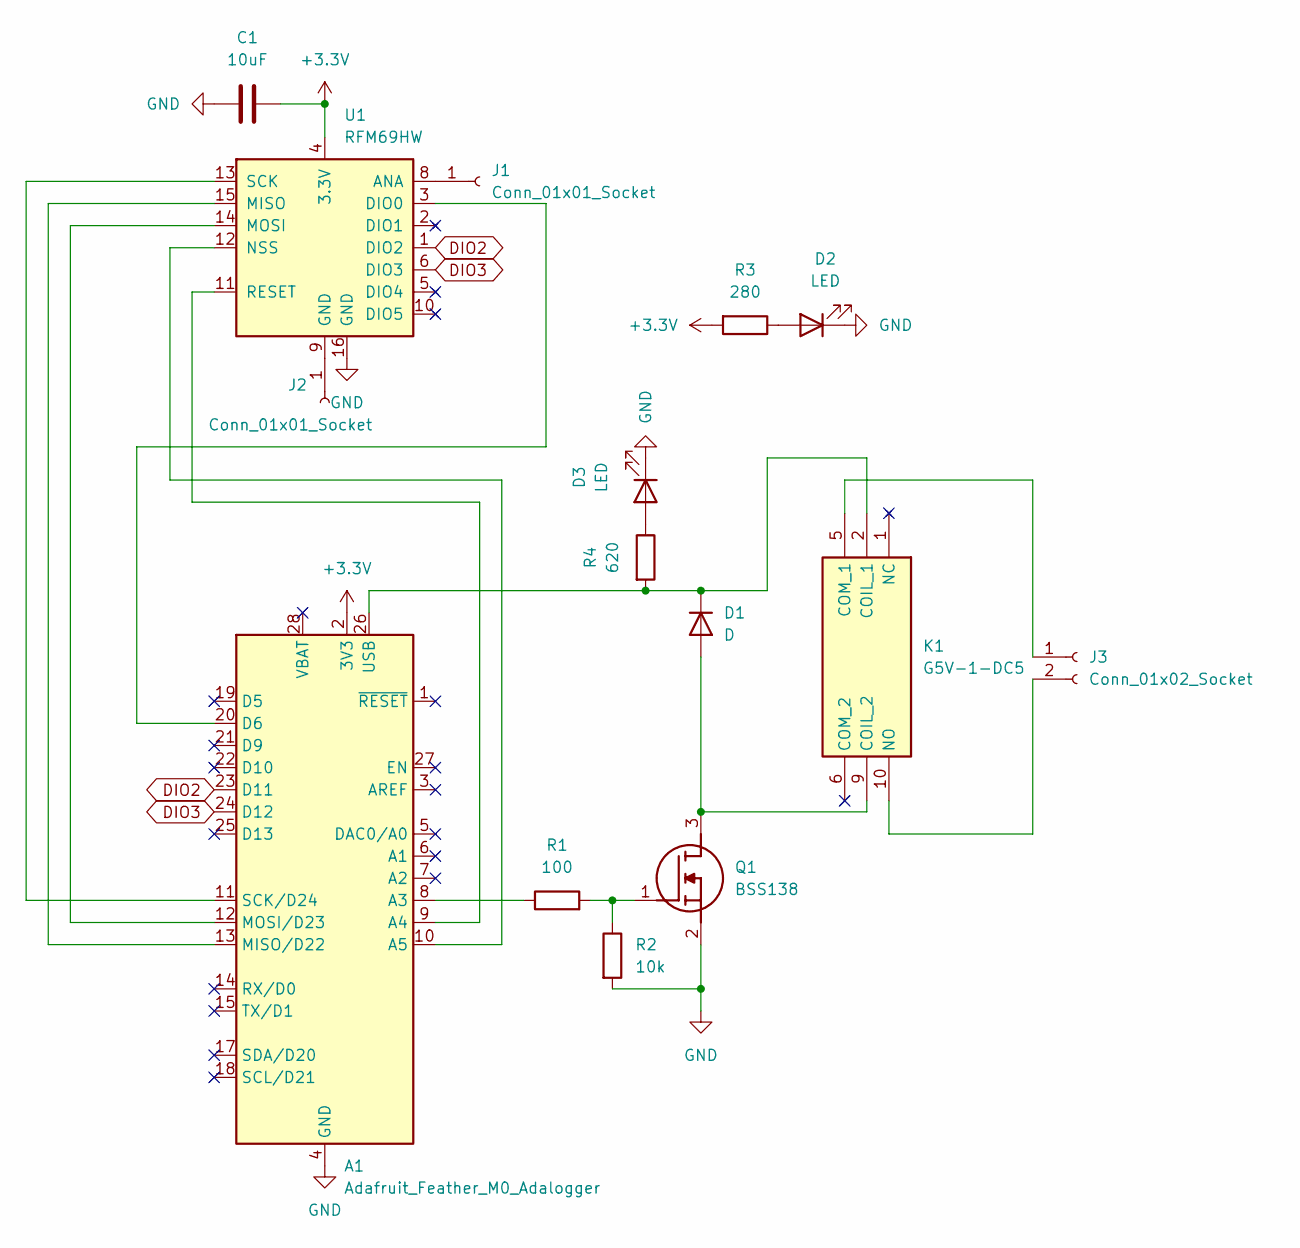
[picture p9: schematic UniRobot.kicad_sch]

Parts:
A1: Adafruit_Feather_M0_Adalogger; Adafruit_Feather
C1: 10uF; C_0805_2012Metric_Pad1.18x1.45mm_HandSolder
D1: D; SODFL3816X120N(diode den vi har)
D2, D3: LED; LED_0805_2012Metric_Pad1.15x1.40mm_HandSolder
J1, J2: Conn_01x01_Socket; PinSocket_1x01_P2.54mm_Vertical
J3: Conn_01x02_Socket; PinSocket_1x02_P2.54mm_Vertical
K1: G5V-1-DC5; G5V1DC24; Mouser Part Number 653-G5V-1-DC5
Q1: BSS138; nmos; Mouser Part Number 512-BSS138
R1: 100; R_0805_2012Metric_Pad1.20x1.40mm_HandSolder
R2: 10k; R_0805_2012Metric_Pad1.20x1.40mm_HandSolder
R3: 280; R_0805_2012Metric_Pad1.20x1.40mm_HandSolder
R4: 620; R_0805_2012Metric_Pad1.20x1.40mm_HandSolder
U1: RFM69HW; RFM69HCW(homemade)

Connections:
+3.3V: A1.2 (3V3), C1.2, R3.2, U1.4 (3.3V)
DIO2: A1.23 (D11), U1.1 (DIO2)
DIO3: A1.24 (D12), U1.6 (DIO3)
GND: A1.4 (GND), A1.16 (GND), C1.1, D2.1 (K), D3.1 (K), Q1.2 (S), R2.2, U1.16 (GND)
unnamed: A1.8 (A3), R1.1
unnamed: A1.9 (A4), U1.11 (RESET)
unnamed: A1.10 (A5), U1.12 (NSS)
unnamed: A1.20 (D6), U1.3 (DIO0)
unnamed: A1.13 (MISO/D22), U1.15 (MISO)
unnamed: A1.12 (MOSI/D23), U1.14 (MOSI)
unnamed: A1.11 (SCK/D24), U1.13 (SCK)
unnamed: A1.26 (USB), D1.1 (K), K1.2 (COIL_1), R4.2
unnamed: D1.2 (A), K1.9 (COIL_2), Q1.3 (D)
unnamed: D2.2 (A), R3.1
unnamed: D3.2 (A), R4.1
unnamed: J1.1, U1.8 (ANA)
unnamed: J2.1, U1.9 (GND)
unnamed: J3.1, K1.5 (COM_1)
unnamed: J3.2, K1.10 (NO)
unnamed: Q1.1 (G), R1.2, R2.1

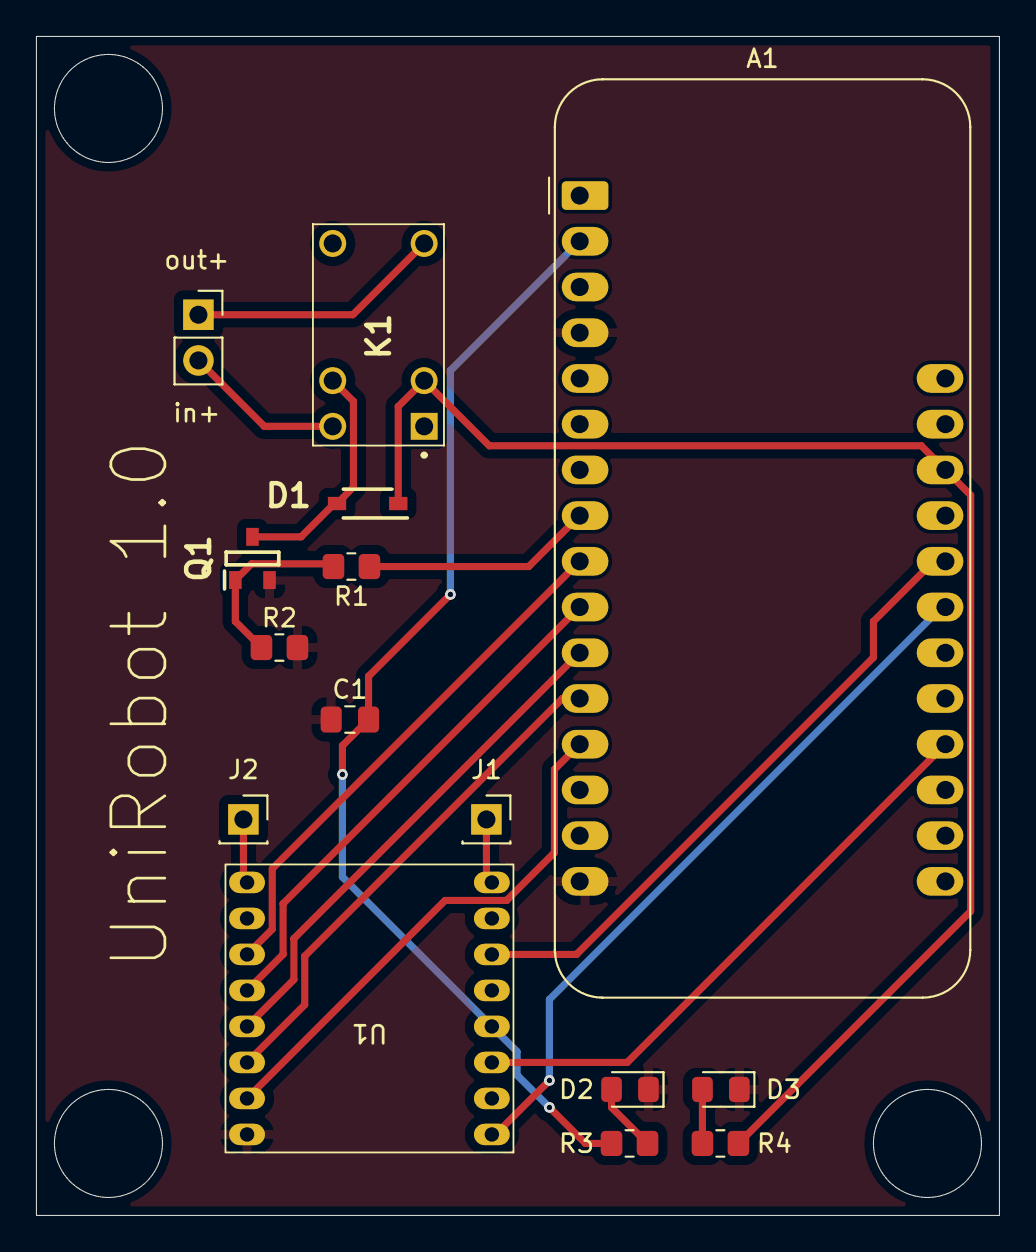
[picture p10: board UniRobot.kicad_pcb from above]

Board: 2 copper layers, 53.5 x 65.5 mm, 15 parts (0 on the bottom side), 20 nets.

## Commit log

2026-03-06 Combined button and joystick for less packages
2026-03-19 Add KiCad PCB files for remote control
    [PCB remote.kicad_pcb, PCB remote.kicad_sch]
2026-03-19 Update PCB design with latest changes
    [PCB remote.kicad_pcb, PCB remote.kicad_sch]
2026-03-19 Restructure repo: move code to remoter/ folder, add pcb/ sibling folder for KiCad files
2026-03-24 ny pcb og noget nyt code glete at gemme de andre dage men her er et push
    [PCB remote.kicad_pcb, PCB remote.kicad_sch]
2026-03-25 lavede robot side pcb.
    [UniRobot.kicad_pcb, UniRobot.kicad_sch]
2026-03-30 filerne virkede ikke så tog dem der virkede og smid ind nu virker de og har added batteri måler
2026-03-30 Har lavet begge pcber om. Remote har ændret struktur for mere håndholdt design og ekstra knapper plus LEDer. roboside har fået ny relay og LEDer
    [PCB remote.kicad_pcb, PCB remote.kicad_sch, UniRobot.kicad_pcb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]
2026-05-27 Add test scripts, PCB design files, and appendix code listings
    [PCB remote.kicad_pcb, PCB remote.kicad_sch, latency_1.2_kbps_20260520_152502.csv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]
